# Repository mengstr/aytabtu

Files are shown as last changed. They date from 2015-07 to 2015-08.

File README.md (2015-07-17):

# AYTABTU

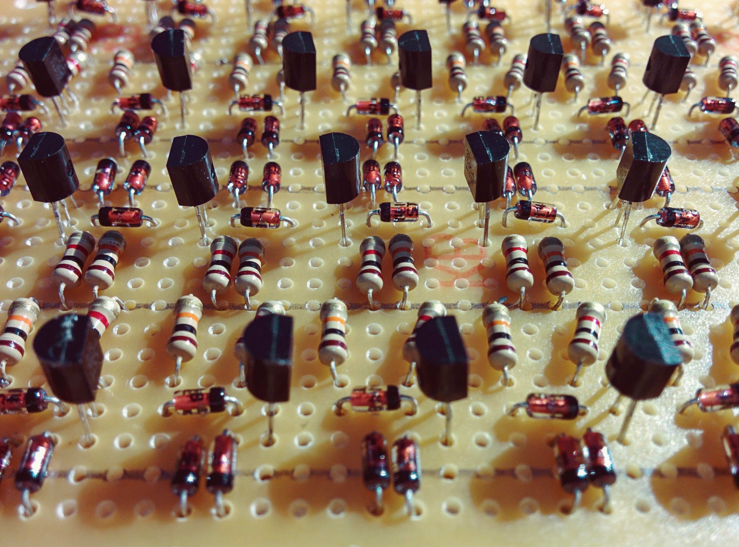
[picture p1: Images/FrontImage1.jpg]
Artful picture of a protoboard

**[All Your Transistors Are Belong to Us] - A computer built from discrete parts**

This is my attempt of building a complete computer using only discrete parts like transistors, diodes, capactitors and resistors.

Just to get warmed up a bit I've started designing an UART capable of transmiting and receiving serial data in 300 bps.

I plan to make proper PCBs for the boards that I require a lot of, like memory, registers and ALU-slices, but many of the more or less one-off boards will be made on standard donut-perfboard with thru-hole parts.

## Credits
I've used, collected, gleaned, stolen, borrowed and been inspired by the information on the following web sites:

Donut pcb layout creator - [code.google.com/p/diy-layout-creator/](https://code.google.com/p/diy-layout-creator/)  
Ring counter - [vk2zay.net/article/201](http://www.vk2zay.net/article/201)  
Asymetric multivibrator - [4qdtec.com/mvibs.html](http://www.4qdtec.com/mvibs.html)  
Single cycle CPU - [eecg.toronto.edu/~moshovos/ECE243-07/...](http://www.eecg.toronto.edu/~moshovos/ECE243-07/l19-implemenation-single-cycle.html)  
Binary incrementer - [letslearncomputing.blogspot.com/2013/....](http://letslearncomputing.blogspot.com/2013/03/digital-logic-4-bit-binary-incrementer.html)  
12/8bit cpu - [usti8bit.blogspot.com](usti8bit.blogspot.com/2015_03_01_archive.html)  
8bit ttl cpu - [digitarworld.uw.hu/ttlcpu.html](http://digitarworld.uw.hu/ttlcpu.html)  
ASAP3 Computer - [pong74ls.blogspot.com/...](http://pong74ls.blogspot.com/2013/11/asap-3-almost-simple-as-possible.html)  
Tiny Tim - [northdownfarm.co.uk/rory/tim/tinytim.htm](http://www.northdownfarm.co.uk/rory/tim/tinytim.htm) 

## Links to my own resources
Link to Google Sheets for a [TX faker generator](https://docs.google.com/spreadsheets/d/1nLxUwCidM7_CYKXSP2XA_T4spadFk9zQSKAtxVXUBSM/edit?usp=sharing).

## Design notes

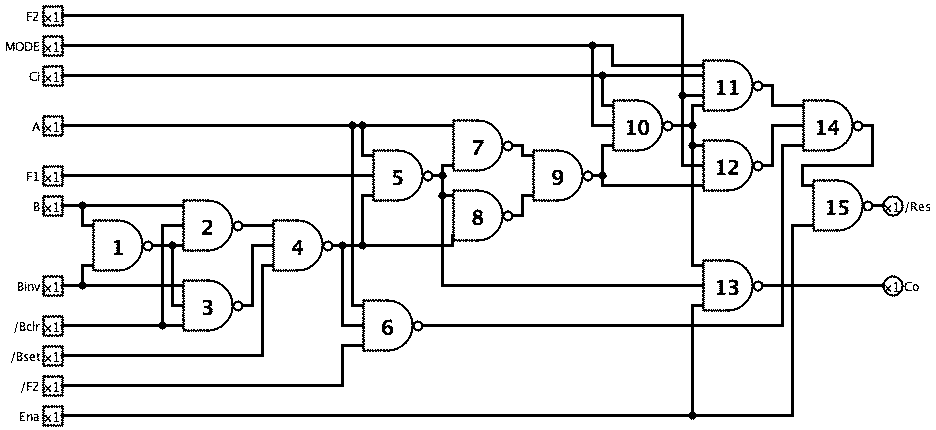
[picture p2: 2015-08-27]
Images/ALUslice.bmp

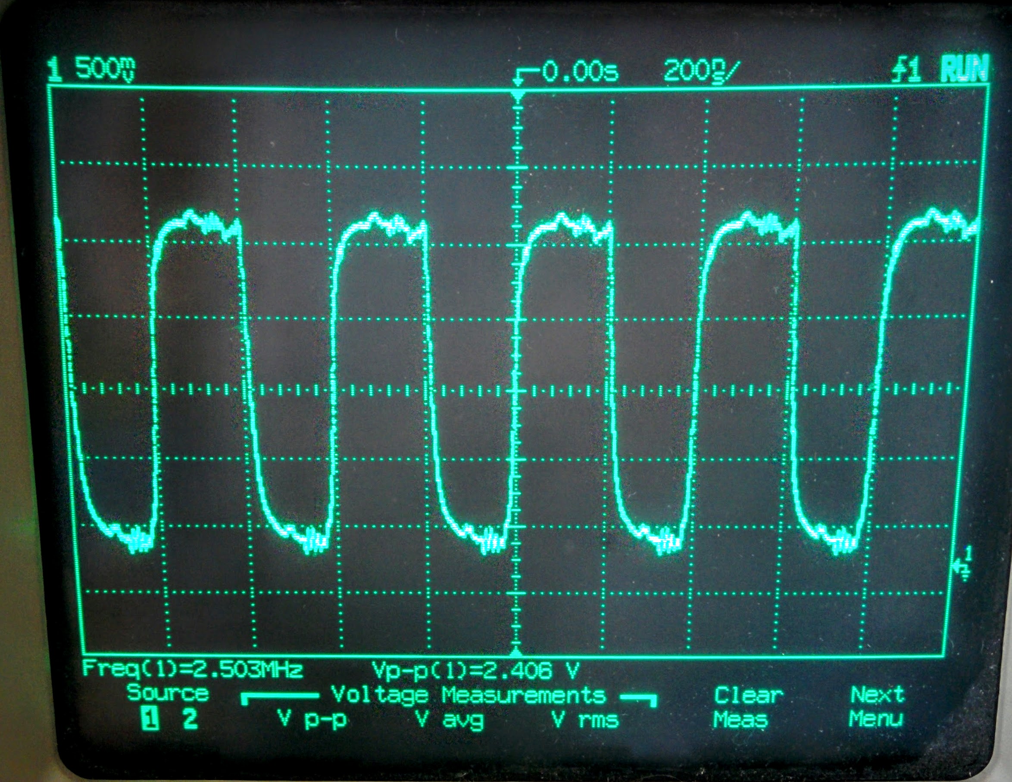
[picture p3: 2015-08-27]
Images/Osc2.5Mhz.jpg

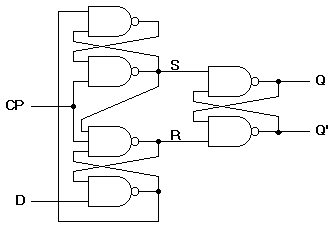
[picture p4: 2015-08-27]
Images/Edge_D_FlipFlop.gif

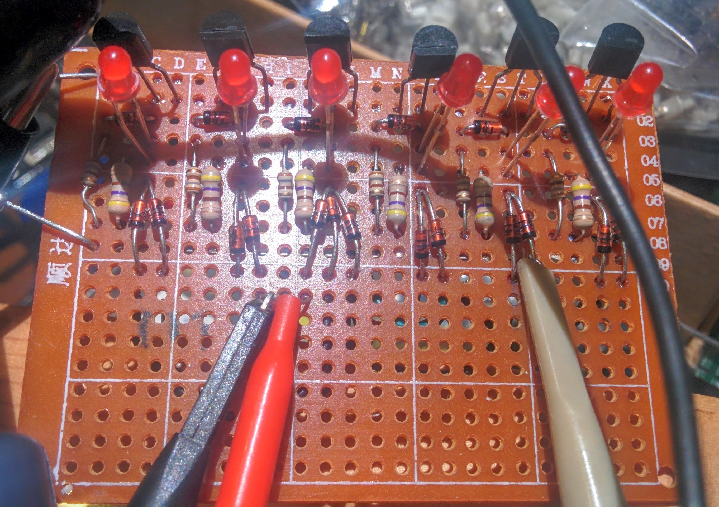
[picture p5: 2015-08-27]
Images/Divider-SiLED.jpg

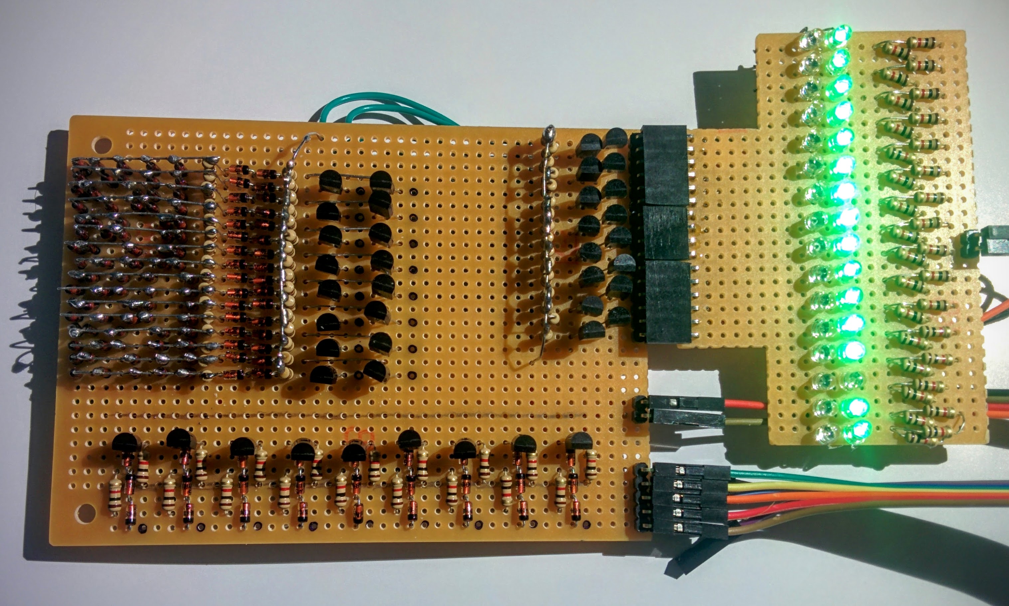
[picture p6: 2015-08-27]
Images/4-to-16decoder.jpg

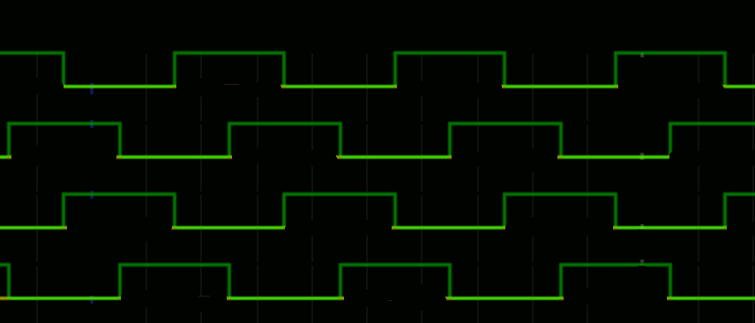
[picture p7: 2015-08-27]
Images/ClockGen4Phase2.png

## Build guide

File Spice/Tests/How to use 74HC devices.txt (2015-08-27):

Make a folder for your schematic(.asc) an save the schematic
into this folder.

Copy 74HC.lib into this folder.

Unzip 74HC.zip on any place. Copy the symbols you need into the
schematic folder.

Place the symbols in your schematic from the schematic folder.
Therefore change the symbol path to your schematic folder.
Press F2, then "Top Directory:your_schematic_path".

Place a SPICE-directive in your schematic.
.include 74HC.lib

Place a V-source with 5V on your schematic. Name it's net VCC.

If you want a logical "0", use a V-source with 0V.

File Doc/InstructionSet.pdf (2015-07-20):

ALU-OPS

0 A | 0 HALT | 0 SET 0x00 | 8 ADD
1 B | 1 | 1 SET 0xFF | 9 SUBTRACT
2 C | 2 | 2 INVERT | 10 ADD w Carry
3 D | 3 | 3 OR | 11 SUB w Carry
4 X | 4 | 4 AND | 12 LEFTSHIFT
5 Y | 5 | 5 XOR | 13 RIGHTSHIFT
6 JH | 6 | 6 INCREMENT | 14
7 JL | 7 | 7 DECREMENT | 15
BRANCH | 0 | 0 | c2 | c1 | c0 | o5 | o4 | o3 | o2 | o1 | o0
HALT | 0 | 0 | 0 | 0 | 0 | x | x | x | x | x | x
FREE1 | 0 | 0 | 0 | 0 | 1 | o5 | o4 | o3 | o2 | o1 | o0
NOP | 0 | 0 | 0 | 1 | 0 | x | x | x | x | x | x
SJMP | 0 | 0 | 0 | 1 | 1 | o5 | o4 | o3 | o2 | o1 | o0
BRAZ | 0 | 0 | 1 | 0 | 0 | o5 | o4 | o3 | o2 | o1 | o0
BRANZ | 0 | 0 | 1 | 0 | 1 | o5 | o4 | o3 | o2 | o1 | o0
BRAC | 0 | 0 | 1 | 1 | 0 | o5 | o4 | o3 | o2 | o1 | o0
BRANC | 0 | 0 | 1 | 1 | 1 | o5 | o4 | o3 | o2 | o1 | o0
LDAI | 0 | 1 | 0 | id7 | id6 | id5 | id4 | id3 | id2 | id1 | id0
LDAZP | 0 | 1 | 1 | a7 | a6 | a5 | a4 | a3 | a2 | a1 | a0
STAZP | 1 | 0 | 0 | a7 | a6 | a5 | a4 | a3 | a2 | a1 | a0
ALU | 1 | 0 | 1 | 0 | op3 | op2 | op1 | op0 | r2 | r1 | r0
CLR | 1 | 0 | 1 | 0 | 0 | 0 | 0 | 0 | r2 | r1 | r0 | r = 0x00
SETFF | 1 | 0 | 1 | 0 | 0 | 0 | 0 | 1 | r2 | r1 | r0 | r = 0xFF
NOT | 1 | 0 | 1 | 0 | 0 | 0 | 1 | 0 | r2 | r1 | r0
OR | 1 | 0 | 1 | 0 | 0 | 0 | 1 | 1 | r2 | r1 | r0 | r = r OR A
AND | 1 | 0 | 1 | 0 | 0 | 1 | 0 | 0 | r2 | r1 | r0 | r = r AND A
XOR | 1 | 0 | 1 | 0 | 0 | 1 | 0 | 1 | r2 | r1 | r0 | r = r XOR A
INC | 1 | 0 | 1 | 0 | 0 | 1 | 1 | 0 | r2 | r1 | r0 | r = r + 1
DEC | 1 | 0 | 1 | 0 | 0 | 1 | 1 | 1 | r2 | r1 | r0 | r = r - 1
ADD | 1 | 0 | 1 | 0 | 1 | 0 | 0 | 0 | r2 | r1 | r0 | r = r + A
SUB | 1 | 0 | 1 | 0 | 1 | 0 | 0 | 1 | r2 | r1 | r0 | r = r - A
ADDC | 1 | 0 | 1 | 0 | 1 | 0 | 1 | 0 | r2 | r1 | r0
SUBC | 1 | 0 | 1 | 0 | 1 | 0 | 1 | 1 | r2 | r1 | r0
LSHIFT | 1 | 0 | 1 | 0 | 1 | 1 | 0 | 0 | r2 | r1 | r0
RSHIFT | 1 | 0 | 1 | 0 | 1 | 1 | 0 | 1 | r2 | r1 | r0
LSHIFTC | 1 | 0 | 1 | 0 | 1 | 1 | 1 | 0 | r2 | r1 | r0
RSHIFTC | 1 | 0 | 1 | 0 | 1 | 1 | 1 | 1 | r2 | r1 | r0
MOVE | 1 | 0 | 1 | 1 | 0 | rs2 | rs1 | rs0 | rd2 | rd1 | rd0
TEST | 1 | 0 | 1 | 1 | 1 | b2 | b1 | b0 | r2 | r1 | r0
PEEK | 1 | 1 | 0 | 0 | 0 | 0 | 0 | p3 | p2 | p1 | p0
POKE | 1 | 1 | 0 | 0 | 0 | 0 | 1 | p3 | p2 | p1 | p0
LDAXY | 1 | 1 | 0 | 0 | 0 | 1 | 0 | 0 | 0 | 0 | 0
STAXY | 1 | 1 | 0 | 0 | 0 | 1 | 0 | 0 | 0 | 0 | 1
JUMP | 1 | 1 | 0 | 0 | 0 | 1 | 0 | 0 | 0 | 1 | 0
CALL | 1 | 1 | 0 | 0 | 0 | 1 | 0 | 0 | 0 | 1 | 1
RET | 1 | 1 | 0 | 0 | 0 | 1 | 0 | 0 | 1 | 0 | 0
| 1 | 1 | 0 | 0 | 0 | 1 | 0 | 0 | 1 | 0 | 1
CLRC | 1 | 1 | 0 | 0 | 0 | 1 | 0 | 0 | 1 | 1 | 0
SETC | 1 | 1 | 0 | 0 | 0 | 1 | 0 | 0 | 1 | 1 | 1
LDPML | 1 | 1 | 0 | 0 | 0 | 1 | 0 | 1 | 0 | 0 | 0
LDPMH | 1 | 1 | 0 | 0 | 0 | 1 | 0 | 1 | 0 | 0 | 1
STPML | 1 | 1 | 0 | 0 | 0 | 1 | 0 | 1 | 0 | 1 | 0
STPMH | 1 | 1 | 0 | 0 | 0 | 1 | 0 | 1 | 0 | 1 | 1
REGISTER | CONDITIONS

Main working register/accumulator

General register

General register | NEVER
General register | ALWAYS
General register/High memory pointer | Z-flag set
General register/Low memory pointer | Z-flag clear
High memory pointer for jumps/calls | C-flag set | LEFTSHIFT w Carry
Low memory pointer for jumps/call | C-flag clear | RIGHTSHIFT w Carry

Conditional "c" relative jump to (+/-)offset indicated by "o"

Stop execution

Do nothing, just continue execution

Jump between -31 and +32 bytes relative from PC

If Zeroflag=1 then jump between -31 and +32 bytes relative from PC

If Zeroflag=0 then jump between -31 and +32 bytes relative from PC

If Carry=1 then jump between -31 and +32 bytes relative from PC

If Carry=0 then jump between -31 and +32 bytes relative from PC

Load immediate data "id" into A

Load value of RAM in areas 0x00..0xFF into A

Store value of A into RAM in areas 0x00..0xFF

Perform the operation "op" on register "r"

r = r XOR 0xFF

r = r + A + carry

r = r - A - carry

r = r << 1, lsb=0

r = r >> 1, msb=0

r = r << 1, lsb=carry

r = r >> 1, msb=carry

Copy (move) register "rs" to register "rd"

Test if bit "b" is set in register "r" and update Z-flag

Load value of i/o port "p" into A

Store value of A into i/o port "p"

Load value of RAM pointed to by X/Y register pair into A-register

Store value of A into RAM pointed to by X/Y register pair

Jump to address pointed to by JH/JL

Jump to address pointed to by JH/JL, update PCHOLD with current PC

Return from CALL by loading PC with values from PCHOLD

Clear Carry flag

Set Clarry flag

Load Low byte (bit 0..7) from Program Memry pointed to by XY into A

Load High byte (bit 8..10) from Program Memry pointed to by XY into A

Store A into Low byte (bit 0..7) of Program memory pointed to by XY

Store A into High byte (bit 8..10) of Program memory pointed to by X

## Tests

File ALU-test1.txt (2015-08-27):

$ 1 0.000005 10.200277308269968 50 5 50
150 240 176 304 176 0 2 0
150 240 240 304 240 0 2 0
150 480 96 544 96 0 2 0
150 640 80 704 80 0 2 0
150 640 144 704 144 0 2 0
150 640 208 704 208 0 2 0
150 448 400 512 400 0 2 0
150 448 480 512 480 0 2 0
150 448 560 528 560 0 2 0
150 448 640 528 640 0 2 0
150 720 448 720 512 0 3 0
150 832 448 832 512 0 3 0
150 928 320 1008 320 0 2 0
154 336 160 416 160 0 2 0
154 704 320 768 320 0 2 0
154 832 304 896 304 0 2 0
152 880 112 960 112 0 4 0
152 480 176 544 176 0 2 0
152 768 576 768 640 0 2 0
I 480 240 544 240 0 0.5
I 320 384 384 384 0 0.5
I 320 416 384 416 0 0.5
I 336 464 384 464 0 0.5
I 320 576 368 576 0 0.5
w 704 80 880 80 0
w 880 96 736 96 0
w 736 96 736 144 0
w 736 144 704 144 0
w 704 208 752 208 0
w 752 208 752 128 0
w 752 128 880 128 0
w 304 176 320 176 0
w 320 176 336 176 0
w 240 160 160 160 0
w 240 192 160 192 0
w 240 224 160 224 0
w 240 256 160 256 0
w 480 240 464 240 0
w 464 240 464 192 0
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
L 160 32 144 32 0 0 false 5 0
L 160 128 144 128 0 0 false 5 0
L 160 160 144 160 0 0 false 5 0
L 160 192 144 192 0 0 false 5 0
L 160 224 144 224 0 0 false 5 0
L 160 256 144 256 0 0 false 5 0
L 160 464 144 464 0 0 false 5 0
L 160 576 144 576 0 0 false 5 0
M 1024 656 1040 656 0 2.5
M 1040 112 1056 112 0 2.5
x 160 26 182 29 0 24 Ci
x 162 123 208 126 0 24 invA
x 162 152 178 155 0 24 A
x 162 186 204 189 0 24 enA
x 163 218 179 221 0 24 B
x 160 249 202 252 0 24 enB
x 158 456 186 459 0 24 F0
x 157 568 185 571 0 24 F1
x 968 646 998 649 0 24 Co
x 986 101 1024 104 0 24 Out

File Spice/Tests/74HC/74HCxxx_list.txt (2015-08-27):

List of implemented ICs.
x implemented

74HC00 x
74HC01 
74HC02 x
74HC03 x
74HC04 x
74HC08 x
74HC10 x
74HC11 x
74HC14 x
74HC20 x
74HC21 x
74HC27 x
74HC30 x
74HC32 x
74HC42	
74HC51 x
74HC58 x
74HC73
74HC74 x
74HC75
74HC76
74HC85
74HC86 x
74HC93
74HC107 x
74HC109 x
74HC112 x
74HC113
74HC123 x
74HC123A x
74HC125 x
74HC126
74HC132 x
74HC133
74HC137
74HC138 x
74HC139 x
74HC147
74HC148
74HC151 x 
74HC153 x
74HC154
74HC155
74HC157 x
74HC158 
74HC160
74HC161 x
74HC163 x
74HC164 x
74HC165 x
74HC166 x
74HC173
74HC174
74HC175
74HC190
74HC191 x
74HC192
74HC193
74HC194 x
74HC195 x
74HC221 x
74HC221A x
74HC237
74HC238 x
74HC240
74HC241
74HC244
74HC245 x
74HC251 x 
74HC253 x
74HC257 x
74HC258
74HC259
74HC266
74HC273
74HC283 x
74HC294
74HC297
74HC299
74HC365
74HC366
74HC367
74HC368
74HC373 x
74HC374 x
74HC377
74HC390 x
74HC393 x
74HC533
74HC540
74HC541
74HC563
74HC564
74HC573 (74HC373)
74HC574 (74HC374)
74HC590
74HC595
74HC620
74HC640
74HC646
74HC670
74HC688
74HC698
74HC4017 x
7HC4538

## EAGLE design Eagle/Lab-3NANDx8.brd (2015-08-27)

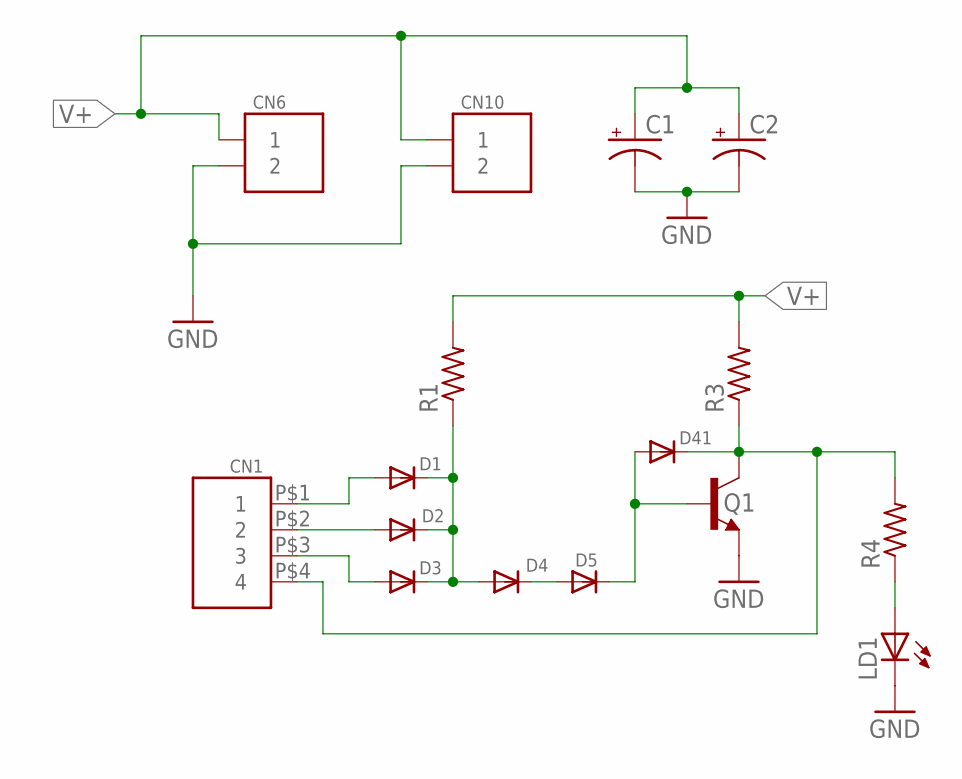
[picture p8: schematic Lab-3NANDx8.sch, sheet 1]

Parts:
C1, C2: CPOL-USE2.5-5; E2,5-5
CN1: HD4
CN6, CN10: HD2
D1, D2, D3, D4, D5: DIODE-6.3; DO35-6.3
D41: DIODE-7.6; DO35-7.6
LD1: LED3MM; 3MM
Q1: 2N3904-1; TO92BH
R1, R3, R4: R1/8-7.6MM; R0125-7.6

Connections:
GND: C1.-, C2.-, CN6.P$2 (2), CN10.P$2 (2), LD1.C, Q1.1 (E); also elsewhere on the board
unnamed: CN1.P$1 (1), D1.A
unnamed: CN1.P$2 (2), D2.A
unnamed: CN1.P$3 (3), D3.A
unnamed: D1.C, D2.C, D3.C, D4.A, R1.1
unnamed: D4.C, D5.A
unnamed: D5.C, D41.A, Q1.2 (B)
unnamed: LD1.A, R4.1
unnamed: CN1.P$4 (4), D41.C, Q1.3 (C), R3.1, R4.2
V+: C1.+, C2.+, CN6.P$1 (1), CN10.P$1 (1), R1.2, R3.2; also elsewhere on the board

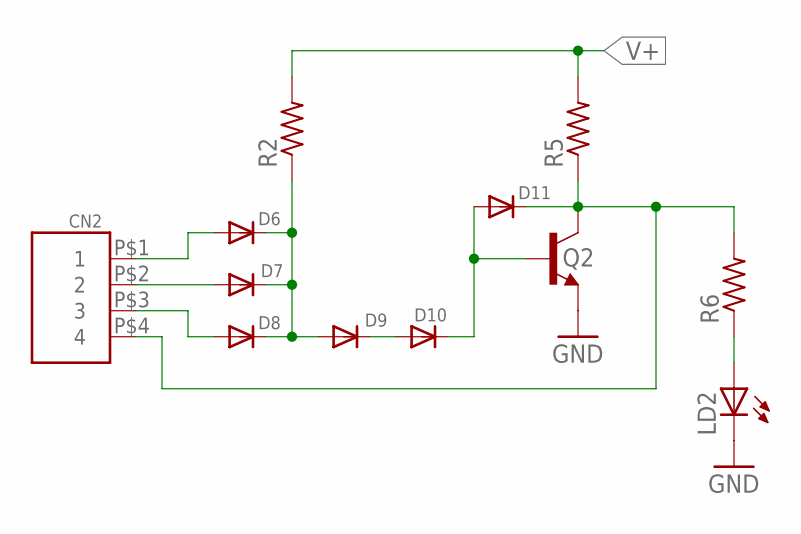
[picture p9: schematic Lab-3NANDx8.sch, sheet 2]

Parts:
CN2: HD4
D6, D7, D8, D9, D10: DIODE-6.3; DO35-6.3
D11: DIODE-7.6; DO35-7.6
LD2: LED3MM; 3MM
Q2: 2N3904-1; TO92BH
R2, R5, R6: R1/8-7.6MM; R0125-7.6

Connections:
GND: LD2.C, Q2.1 (E); also elsewhere on the board
unnamed: CN2.P$1 (1), D6.A
unnamed: CN2.P$2 (2), D7.A
unnamed: CN2.P$3 (3), D8.A
unnamed: D6.C, D7.C, D8.C, D9.A, R2.1
unnamed: D9.C, D10.A
unnamed: D10.C, D11.A, Q2.2 (B)
unnamed: CN2.P$4 (4), D11.C, Q2.3 (C), R5.1, R6.2
unnamed: LD2.A, R6.1
V+: R2.2, R5.2; also elsewhere on the board

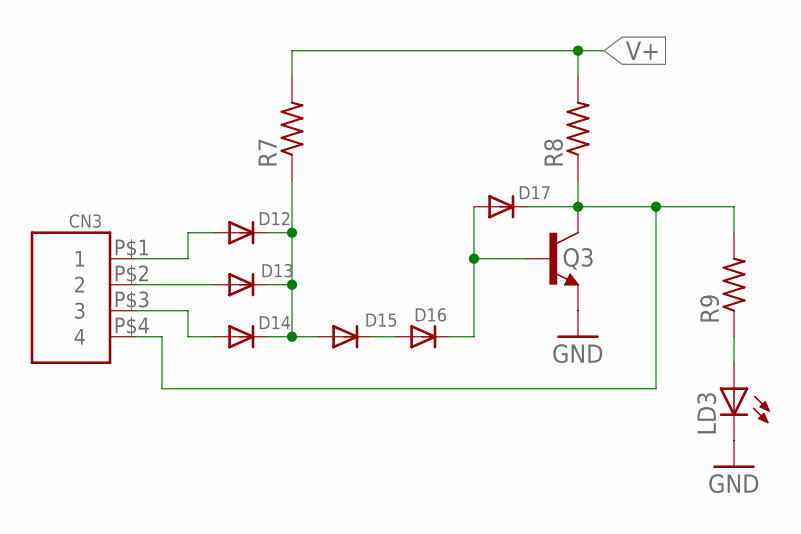
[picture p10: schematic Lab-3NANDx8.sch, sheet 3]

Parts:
CN3: HD4
D12, D13, D14, D15, D16: DIODE-6.3; DO35-6.3
D17: DIODE-7.6; DO35-7.6
LD3: LED3MM; 3MM
Q3: 2N3904-1; TO92BH
R7, R8, R9: R1/8-7.6MM; R0125-7.6

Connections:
GND: LD3.C, Q3.1 (E); also elsewhere on the board
unnamed: CN3.P$1 (1), D12.A
unnamed: CN3.P$2 (2), D13.A
unnamed: CN3.P$3 (3), D14.A
unnamed: D12.C, D13.C, D14.C, D15.A, R7.1
unnamed: D15.C, D16.A
unnamed: D16.C, D17.A, Q3.2 (B)
unnamed: CN3.P$4 (4), D17.C, Q3.3 (C), R8.1, R9.2
unnamed: LD3.A, R9.1
V+: R7.2, R8.2; also elsewhere on the board

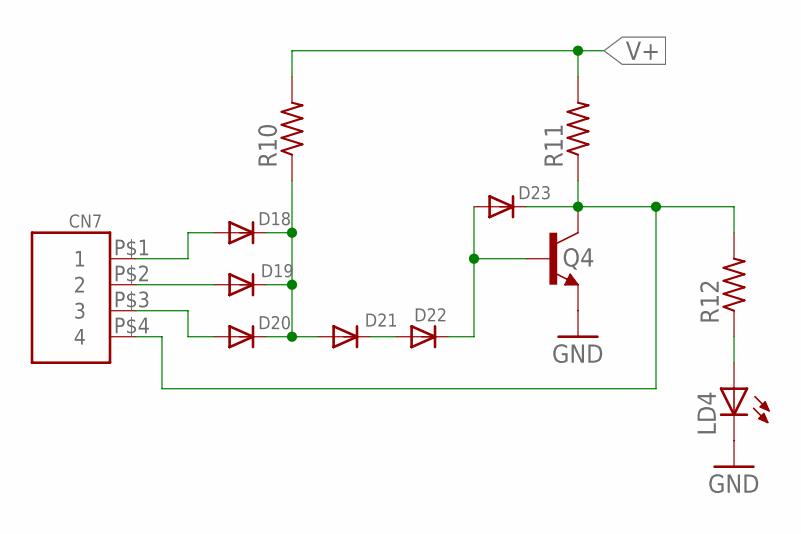
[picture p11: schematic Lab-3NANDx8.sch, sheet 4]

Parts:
CN7: HD4
D18, D19, D20, D21, D22: DIODE-6.3; DO35-6.3
D23: DIODE-7.6; DO35-7.6
LD4: LED3MM; 3MM
Q4: 2N3904-1; TO92BH
R10, R11, R12: R1/8-7.6MM; R0125-7.6

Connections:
GND: LD4.C, Q4.1 (E); also elsewhere on the board
unnamed: CN7.P$1 (1), D18.A
unnamed: CN7.P$2 (2), D19.A
unnamed: CN7.P$3 (3), D20.A
unnamed: D18.C, D19.C, D20.C, D21.A, R10.1
unnamed: D21.C, D22.A
unnamed: D22.C, D23.A, Q4.2 (B)
unnamed: CN7.P$4 (4), D23.C, Q4.3 (C), R11.1, R12.2
unnamed: LD4.A, R12.1
V+: R10.2, R11.2; also elsewhere on the board

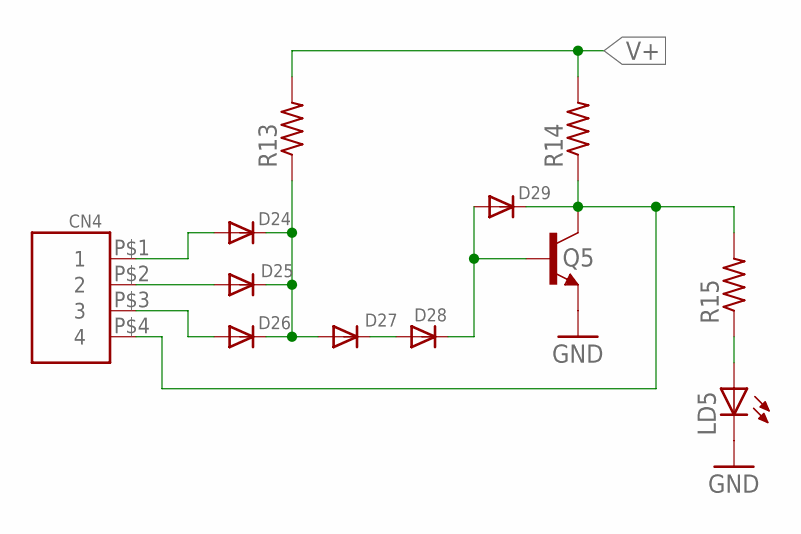
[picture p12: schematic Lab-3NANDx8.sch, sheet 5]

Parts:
CN4: HD4
D24, D25, D26, D27, D28: DIODE-6.3; DO35-6.3
D29: DIODE-7.6; DO35-7.6
LD5: LED3MM; 3MM
Q5: 2N3904-1; TO92BH
R13, R14, R15: R1/8-7.6MM; R0125-7.6

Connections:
GND: LD5.C, Q5.1 (E); also elsewhere on the board
unnamed: CN4.P$1 (1), D24.A
unnamed: CN4.P$2 (2), D25.A
unnamed: CN4.P$3 (3), D26.A
unnamed: D24.C, D25.C, D26.C, D27.A, R13.1
unnamed: D27.C, D28.A
unnamed: D28.C, D29.A, Q5.2 (B)
unnamed: CN4.P$4 (4), D29.C, Q5.3 (C), R14.1, R15.2
unnamed: LD5.A, R15.1
V+: R13.2, R14.2; also elsewhere on the board

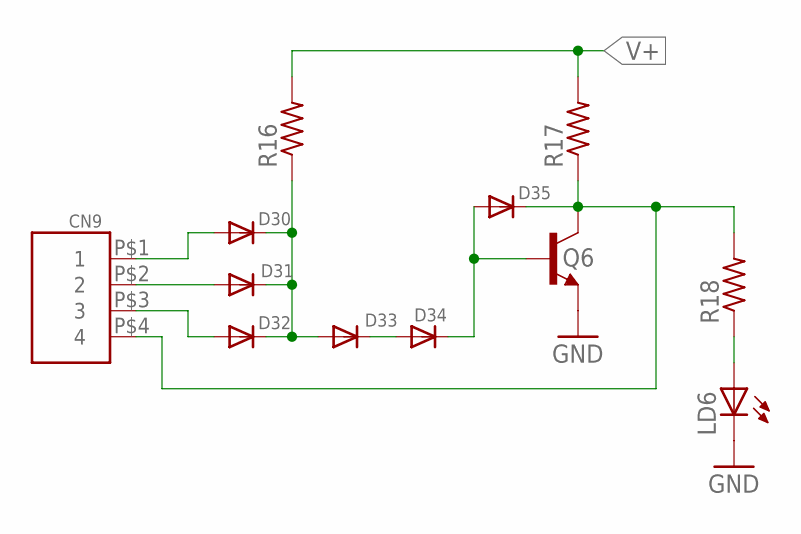
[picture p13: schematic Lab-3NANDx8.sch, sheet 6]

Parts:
CN9: HD4
D30, D31, D32, D33, D34: DIODE-6.3; DO35-6.3
D35: DIODE-7.6; DO35-7.6
LD6: LED3MM; 3MM
Q6: 2N3904-1; TO92BH
R16, R17, R18: R1/8-7.6MM; R0125-7.6

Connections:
GND: LD6.C, Q6.1 (E); also elsewhere on the board
unnamed: CN9.P$1 (1), D30.A
unnamed: CN9.P$2 (2), D31.A
unnamed: CN9.P$3 (3), D32.A
unnamed: D30.C, D31.C, D32.C, D33.A, R16.1
unnamed: D33.C, D34.A
unnamed: D34.C, D35.A, Q6.2 (B)
unnamed: CN9.P$4 (4), D35.C, Q6.3 (C), R17.1, R18.2
unnamed: LD6.A, R18.1
V+: R16.2, R17.2; also elsewhere on the board

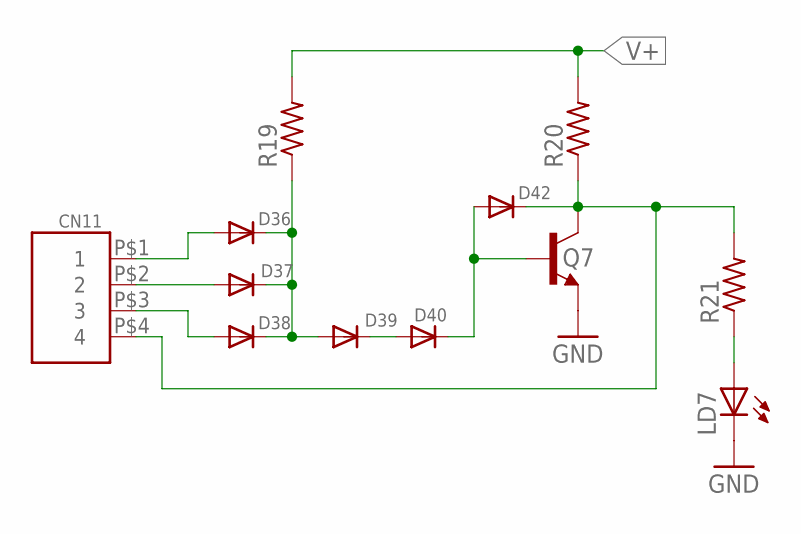
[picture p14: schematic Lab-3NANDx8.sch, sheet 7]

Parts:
CN11: HD4
D36, D37, D38, D39, D40: DIODE-6.3; DO35-6.3
D42: DIODE-7.6; DO35-7.6
LD7: LED3MM; 3MM
Q7: 2N3904-1; TO92BH
R19, R20, R21: R1/8-7.6MM; R0125-7.6

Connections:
GND: LD7.C, Q7.1 (E); also elsewhere on the board
unnamed: CN11.P$1 (1), D36.A
unnamed: CN11.P$2 (2), D37.A
unnamed: CN11.P$3 (3), D38.A
unnamed: D36.C, D37.C, D38.C, D39.A, R19.1
unnamed: D39.C, D40.A
unnamed: D40.C, D42.A, Q7.2 (B)
unnamed: CN11.P$4 (4), D42.C, Q7.3 (C), R20.1, R21.2
unnamed: LD7.A, R21.1
V+: R19.2, R20.2; also elsewhere on the board

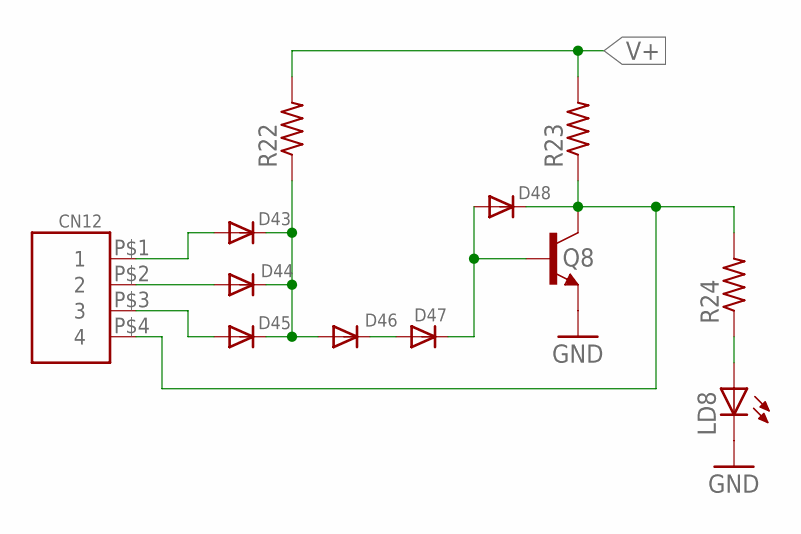
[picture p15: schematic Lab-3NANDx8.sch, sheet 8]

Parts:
CN12: HD4
D43, D44, D45, D46, D47: DIODE-6.3; DO35-6.3
D48: DIODE-7.6; DO35-7.6
LD8: LED3MM; 3MM
Q8: 2N3904-1; TO92BH
R22, R23, R24: R1/8-7.6MM; R0125-7.6

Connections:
GND: LD8.C, Q8.1 (E); also elsewhere on the board
unnamed: CN12.P$1 (1), D43.A
unnamed: CN12.P$2 (2), D44.A
unnamed: CN12.P$3 (3), D45.A
unnamed: D43.C, D44.C, D45.C, D46.A, R22.1
unnamed: D46.C, D47.A
unnamed: D47.C, D48.A, Q8.2 (B)
unnamed: CN12.P$4 (4), D48.C, Q8.3 (C), R23.1, R24.2
unnamed: LD8.A, R24.1
V+: R22.2, R23.2; also elsewhere on the board

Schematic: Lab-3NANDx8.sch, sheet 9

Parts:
CN5: HD4
D49, D50, D51, D52, D53: DIODE-6.3; DO35-6.3
D54: DIODE-7.6; DO35-7.6
LD9: LED3MM; 3MM
Q9: 2N3904-1; TO92BH
R25, R26, R27: R1/8-7.6MM; R0125-7.6

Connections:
GND: LD9.C, Q9.1 (E); also elsewhere on the board
unnamed: CN5.P$1 (1), D49.A
unnamed: CN5.P$2 (2), D50.A
unnamed: CN5.P$3 (3), D51.A
unnamed: D49.C, D50.C, D51.C, D52.A, R25.1
unnamed: D52.C, D53.A
unnamed: D53.C, D54.A, Q9.2 (B)
unnamed: CN5.P$4 (4), D54.C, Q9.3 (C), R26.1, R27.2
unnamed: LD9.A, R27.1
V+: R25.2, R26.2; also elsewhere on the board

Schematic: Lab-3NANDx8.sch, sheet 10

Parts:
CN14: HD4
D55, D56, D57, D58, D59: DIODE-6.3; DO35-6.3
D60: DIODE-7.6; DO35-7.6
LD10: LED3MM; 3MM
Q10: 2N3904-1; TO92BH
R28, R29, R30: R1/8-7.6MM; R0125-7.6

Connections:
GND: LD10.C, Q10.1 (E); also elsewhere on the board
unnamed: CN14.P$1 (1), D55.A
unnamed: CN14.P$2 (2), D56.A
unnamed: CN14.P$3 (3), D57.A
unnamed: D55.C, D56.C, D57.C, D58.A, R28.1
unnamed: D58.C, D59.A
unnamed: D59.C, D60.A, Q10.2 (B)
unnamed: CN14.P$4 (4), D60.C, Q10.3 (C), R29.1, R30.2
unnamed: LD10.A, R30.1
V+: R28.2, R29.2; also elsewhere on the board

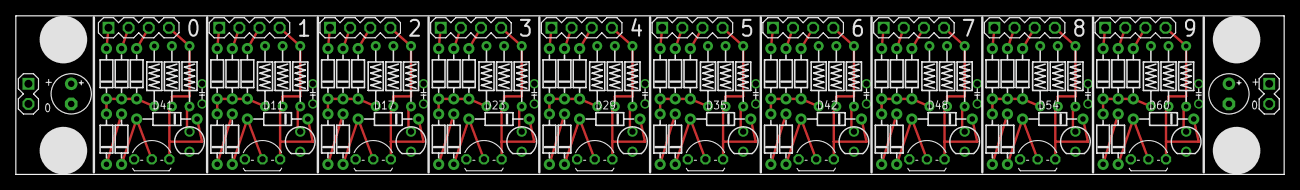
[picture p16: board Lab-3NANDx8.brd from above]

Board: 2 copper layers, 160.0 x 20.0 mm, 124 parts (0 on the bottom side), 82 nets.

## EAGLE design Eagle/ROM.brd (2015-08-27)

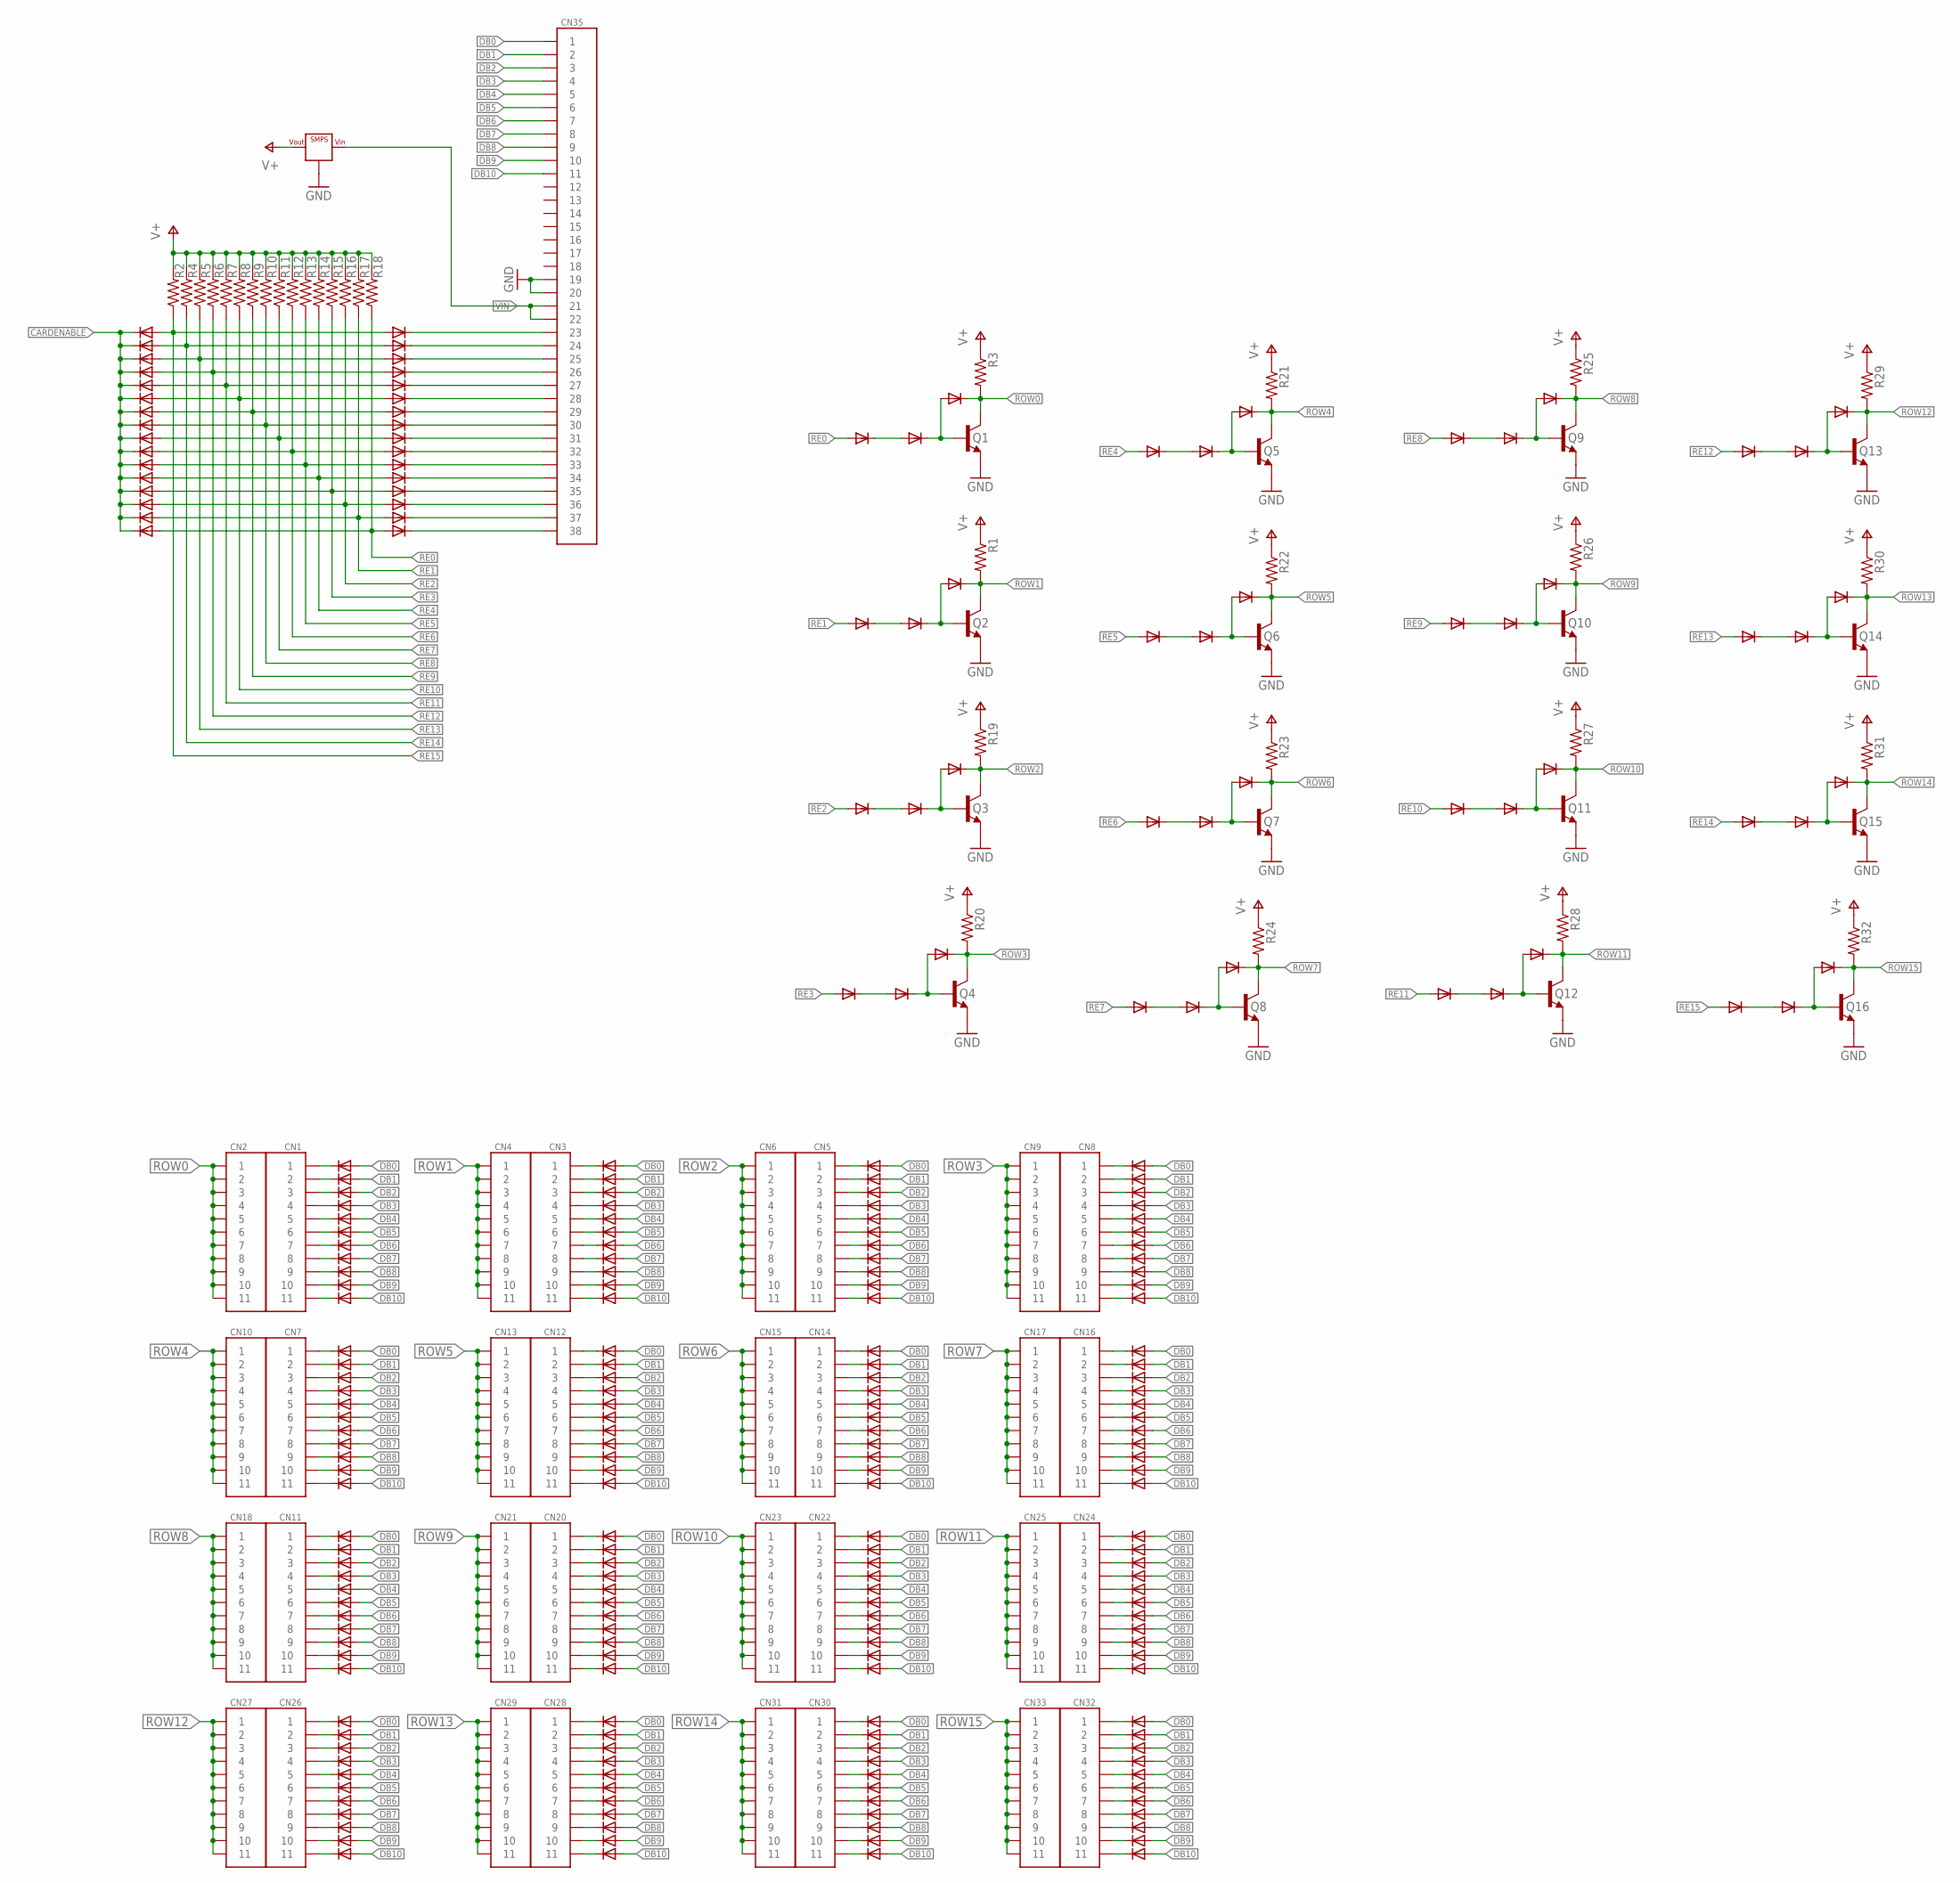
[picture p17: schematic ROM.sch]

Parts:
CN1, CN2, CN3, CN4, CN5, CN6, CN7, CN8, CN9, CN10, CN11, CN12, CN13, CN14, CN15, CN16, CN17, CN18, CN20, CN21, CN22, CN23, CN24, CN25, CN26, CN27, CN28, CN29, CN30, CN31, CN32, CN33: HD11
CN35: HD38-HP; HD38-HOLEPAD
D1, D2, D3, D4, D5, D6, D7, D8, D9, D10, D11, D12, D13, D14, D15, D16, D17, D18, D19, D20, D21, D22, D23, D24, D25, D26, D27, D28, D29, D30, D31, D32, D33, D34, D35, D36, D37, D38, D39, D40, D41, D42, D43, D44, D45, D46, D47, D48, D49, D50, D51, D52, D53, D54, D55, D56, D57, D58, D59, D60, D61, D62, D63, D64, D65, D66, D67, D68, D69, D70, D71, D72, D73, D74, D75, D76, D77, D78, D79, D80, D81, D82, D83, D84, D85, D86, D87, D88, D89, D90, D91, D92, D93, D94, D95, D96, D97, D98, D99, D100, D101, D102, D103, D104, D105, D106, D107, D108, D109, D110, D111, D112, D113, D114, D115, D116, D117, D118, D119, D120, D121, D122, D123, D124, D125, D126, D127, D128, D129, D130, D131, D132, D133, D134, D135, D136, D137, D138, D139, D140, D141, D142, D143, D144, D145, D146, D147, D148, D149, D150, D151, D152, D153, D154, D155, D156, D157, D158, D159, D160, D161, D162, D163, D164, D165, D166, D167, D168, D169, D170, D171, D172, D173, D174, D175, D176: DIODE-6.3; DO35-6.3
D177, D178, D179, D180, D181, D182, D183, D184, D185, D186, D187, D188, D189, D190, D191, D192, D193, D194, D195, D196, D197, D198, D199, D200, D201, D202, D203, D204, D205, D206, D207, D208, D209, D210, D211, D212, D213, D214, D215, D216, D217, D218, D219, D220, D221, D222, D223, D224, D225, D226, D227, D228, D229, D230, D231, D232, D233, D234, D235, D236, D237, D238, D239, D240, D241, D242, D243, D244, D245, D246, D247, D248, D249, D250, D251, D252, D253, D254, D255, D256: DIODE-5.08; DO35-5.08
Q1, Q2, Q3, Q4, Q5, Q6, Q7, Q8, Q9, Q10, Q11, Q12, Q13, Q14, Q15, Q16: BC547-STRAIGHT; TO92-S-CBE
R1, R2, R3, R4, R5, R6, R7, R8, R9, R10, R11, R12, R13, R14, R15, R16, R17, R18, R19, R20, R21, R22, R23, R24, R25, R26, R27, R28, R29, R30, R31, R32: R1/8-6MM; R0125-6.3
VR1: SMPS; BUCK1722

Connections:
CARDENABLE: D182.C, D183.C, D184.C, D185.C, D186.C, D187.C, D188.C, D189.C, D190.C, D191.C, D192.C, D193.C, D194.C, D195.C, D196.C, D197.C
DB0: CN35.P1@1 (1), CN35.P1@2 (1), D1.A, D12.A, D23.A, D34.A, D45.A, D56.A, D67.A, D78.A, D89.A, D100.A, D111.A, D122.A, D133.A, D144.A, D155.A, D166.A
DB1: CN35.P2@1 (2), CN35.P2@2 (2), D2.A, D13.A, D24.A, D35.A, D46.A, D57.A, D68.A, D79.A, D90.A, D101.A, D112.A, D123.A, D134.A, D145.A, D156.A, D167.A
DB2: CN35.P3@1 (3), CN35.P3@2 (3), D3.A, D14.A, D25.A, D36.A, D47.A, D58.A, D69.A, D80.A, D91.A, D102.A, D113.A, D124.A, D135.A, D146.A, D157.A, D168.A
DB3: CN35.P4@1 (4), CN35.P4@2 (4), D4.A, D15.A, D26.A, D37.A, D48.A, D59.A, D70.A, D81.A, D92.A, D103.A, D114.A, D125.A, D136.A, D147.A, D158.A, D169.A
DB4: CN35.P5@1 (5), CN35.P5@2 (5), D5.A, D16.A, D27.A, D38.A, D49.A, D60.A, D71.A, D82.A, D93.A, D104.A, D115.A, D126.A, D137.A, D148.A, D159.A, D170.A
DB5: CN35.P6@1 (6), CN35.P6@2 (6), D6.A, D17.A, D28.A, D39.A, D50.A, D61.A, D72.A, D83.A, D94.A, D105.A, D116.A, D127.A, D138.A, D149.A, D160.A, D171.A
DB6: CN35.P7@1 (7), CN35.P7@2 (7), D7.A, D18.A, D29.A, D40.A, D51.A, D62.A, D73.A, D84.A, D95.A, D106.A, D117.A, D128.A, D139.A, D150.A, D161.A, D172.A
DB7: CN35.P8@1 (8), CN35.P8@2 (8), D8.A, D19.A, D30.A, D41.A, D52.A, D63.A, D74.A, D85.A, D96.A, D107.A, D118.A, D129.A, D140.A, D151.A, D162.A, D173.A
DB8: CN35.P9@1 (9), CN35.P9@2 (9), D9.A, D20.A, D31.A, D42.A, D53.A, D64.A, D75.A, D86.A, D97.A, D108.A, D119.A, D130.A, D141.A, D152.A, D163.A, D174.A
DB9: CN35.P10@1 (10), CN35.P10@2 (10), D10.A, D21.A, D32.A, D43.A, D54.A, D65.A, D76.A, D87.A, D98.A, D109.A, D120.A, D131.A, D142.A, D153.A, D164.A, D175.A
DB10: CN35.P11@1 (11), CN35.P11@2 (11), D11.A, D22.A, D33.A, D44.A, D55.A, D66.A, D77.A, D88.A, D99.A, D110.A, D121.A, D132.A, D143.A, D154.A, D165.A, D176.A
GND: CN35.P19@1 (19), CN35.P19@2 (19), CN35.P20@1 (20), CN35.P20@2 (20), Q1.E, Q2.E, Q3.E, Q4.E, Q5.E, Q6.E, Q7.E, Q8.E, Q9.E, Q10.E, Q11.E, Q12.E, Q13.E, Q14.E, Q15.E, Q16.E, VR1.GND@1 (GND), VR1.GND@2 (GND), VR1.GND@3 (GND), VR1.GND@4 (GND)
unnamed: CN1.P$1 (1), D1.C
unnamed: CN1.P$2 (2), D2.C
unnamed: CN1.P$3 (3), D3.C
unnamed: CN1.P$4 (4), D4.C
unnamed: CN1.P$5 (5), D5.C
unnamed: CN1.P$6 (6), D6.C
unnamed: CN1.P$7 (7), D7.C
unnamed: CN1.P$8 (8), D8.C
unnamed: CN1.P$9 (9), D9.C
unnamed: CN1.P$10 (10), D10.C
unnamed: CN1.P$11 (11), D11.C
unnamed: CN3.P$1 (1), D12.C
unnamed: CN3.P$2 (2), D13.C
unnamed: CN3.P$3 (3), D14.C
unnamed: CN3.P$4 (4), D15.C
unnamed: CN3.P$5 (5), D16.C
unnamed: CN3.P$6 (6), D17.C
unnamed: CN3.P$7 (7), D18.C
unnamed: CN3.P$8 (8), D19.C
unnamed: CN3.P$9 (9), D20.C
unnamed: CN3.P$10 (10), D21.C
unnamed: CN3.P$11 (11), D22.C
unnamed: CN5.P$1 (1), D23.C
unnamed: CN5.P$2 (2), D24.C
unnamed: CN5.P$3 (3), D25.C
unnamed: CN5.P$4 (4), D26.C
unnamed: CN5.P$5 (5), D27.C
unnamed: CN5.P$6 (6), D28.C
unnamed: CN5.P$7 (7), D29.C
unnamed: CN5.P$8 (8), D30.C
unnamed: CN5.P$9 (9), D31.C
unnamed: CN5.P$10 (10), D32.C
unnamed: CN5.P$11 (11), D33.C
unnamed: CN8.P$1 (1), D34.C
unnamed: CN8.P$2 (2), D35.C
unnamed: CN8.P$3 (3), D36.C
unnamed: CN8.P$4 (4), D37.C
unnamed: CN8.P$5 (5), D38.C
unnamed: CN8.P$6 (6), D39.C
unnamed: CN8.P$7 (7), D40.C
unnamed: CN8.P$8 (8), D41.C
unnamed: CN8.P$9 (9), D42.C
unnamed: CN8.P$10 (10), D43.C
unnamed: CN8.P$11 (11), D44.C
unnamed: CN7.P$1 (1), D45.C
unnamed: CN7.P$2 (2), D46.C
unnamed: CN7.P$3 (3), D47.C
unnamed: CN7.P$4 (4), D48.C
unnamed: CN7.P$5 (5), D49.C
unnamed: CN7.P$6 (6), D50.C
unnamed: CN7.P$7 (7), D51.C
unnamed: CN7.P$8 (8), D52.C
unnamed: CN7.P$9 (9), D53.C
unnamed: CN7.P$10 (10), D54.C
unnamed: CN7.P$11 (11), D55.C
unnamed: CN12.P$1 (1), D56.C
unnamed: CN12.P$2 (2), D57.C
unnamed: CN12.P$3 (3), D58.C
unnamed: CN12.P$4 (4), D59.C
unnamed: CN12.P$5 (5), D60.C
unnamed: CN12.P$6 (6), D61.C
unnamed: CN12.P$7 (7), D62.C
unnamed: CN12.P$8 (8), D63.C
unnamed: CN12.P$9 (9), D64.C
unnamed: CN12.P$10 (10), D65.C
unnamed: CN12.P$11 (11), D66.C
unnamed: CN14.P$1 (1), D67.C
unnamed: CN14.P$2 (2), D68.C
unnamed: CN14.P$3 (3), D69.C
unnamed: CN14.P$4 (4), D70.C
unnamed: CN14.P$5 (5), D71.C
unnamed: CN14.P$6 (6), D72.C
unnamed: CN14.P$7 (7), D73.C
unnamed: CN14.P$8 (8), D74.C
unnamed: CN14.P$9 (9), D75.C
unnamed: CN14.P$10 (10), D76.C
unnamed: CN14.P$11 (11), D77.C
unnamed: CN16.P$1 (1), D78.C
unnamed: CN16.P$2 (2), D79.C
unnamed: CN16.P$3 (3), D80.C
unnamed: CN16.P$4 (4), D81.C
unnamed: CN16.P$5 (5), D82.C
unnamed: CN16.P$6 (6), D83.C
unnamed: CN16.P$7 (7), D84.C
unnamed: CN16.P$8 (8), D85.C
unnamed: CN16.P$9 (9), D86.C
unnamed: CN16.P$10 (10), D87.C
unnamed: CN16.P$11 (11), D88.C
unnamed: CN11.P$1 (1), D89.C
unnamed: CN11.P$2 (2), D90.C
unnamed: CN11.P$3 (3), D91.C
unnamed: CN11.P$4 (4), D92.C
unnamed: CN11.P$5 (5), D93.C
unnamed: CN11.P$6 (6), D94.C
unnamed: CN11.P$7 (7), D95.C
unnamed: CN11.P$8 (8), D96.C
unnamed: CN11.P$9 (9), D97.C
unnamed: CN11.P$10 (10), D98.C
unnamed: CN11.P$11 (11), D99.C
unnamed: CN20.P$1 (1), D100.C
unnamed: CN20.P$2 (2), D101.C
unnamed: CN20.P$3 (3), D102.C
unnamed: CN20.P$4 (4), D103.C
unnamed: CN20.P$5 (5), D104.C
unnamed: CN20.P$6 (6), D105.C
unnamed: CN20.P$7 (7), D106.C
unnamed: CN20.P$8 (8), D107.C
unnamed: CN20.P$9 (9), D108.C
unnamed: CN20.P$10 (10), D109.C
unnamed: CN20.P$11 (11), D110.C
unnamed: CN22.P$1 (1), D111.C
unnamed: CN22.P$2 (2), D112.C
unnamed: CN22.P$3 (3), D113.C
unnamed: CN22.P$4 (4), D114.C
unnamed: CN22.P$5 (5), D115.C
unnamed: CN22.P$6 (6), D116.C
unnamed: CN22.P$7 (7), D117.C
unnamed: CN22.P$8 (8), D118.C
unnamed: CN22.P$9 (9), D119.C
unnamed: CN22.P$10 (10), D120.C
unnamed: CN22.P$11 (11), D121.C
unnamed: CN24.P$1 (1), D122.C
unnamed: CN24.P$2 (2), D123.C
unnamed: CN24.P$3 (3), D124.C
unnamed: CN24.P$4 (4), D125.C
unnamed: CN24.P$5 (5), D126.C
unnamed: CN24.P$6 (6), D127.C
unnamed: CN24.P$7 (7), D128.C
unnamed: CN24.P$8 (8), D129.C
unnamed: CN24.P$9 (9), D130.C
unnamed: CN24.P$10 (10), D131.C
unnamed: CN24.P$11 (11), D132.C
unnamed: CN26.P$1 (1), D133.C
unnamed: CN26.P$2 (2), D134.C
unnamed: CN26.P$3 (3), D135.C
unnamed: CN26.P$4 (4), D136.C
unnamed: CN26.P$5 (5), D137.C
unnamed: CN26.P$6 (6), D138.C
unnamed: CN26.P$7 (7), D139.C
unnamed: CN26.P$8 (8), D140.C
unnamed: CN26.P$9 (9), D141.C
unnamed: CN26.P$10 (10), D142.C
unnamed: CN26.P$11 (11), D143.C
unnamed: CN28.P$1 (1), D144.C
unnamed: CN28.P$2 (2), D145.C
unnamed: CN28.P$3 (3), D146.C
unnamed: CN28.P$4 (4), D147.C
unnamed: CN28.P$5 (5), D148.C
unnamed: CN28.P$6 (6), D149.C
unnamed: CN28.P$7 (7), D150.C
unnamed: CN28.P$8 (8), D151.C
unnamed: CN28.P$9 (9), D152.C
unnamed: CN28.P$10 (10), D153.C
unnamed: CN28.P$11 (11), D154.C
unnamed: CN30.P$1 (1), D155.C
unnamed: CN30.P$2 (2), D156.C
unnamed: CN30.P$3 (3), D157.C
unnamed: CN30.P$4 (4), D158.C
unnamed: CN30.P$5 (5), D159.C
unnamed: CN30.P$6 (6), D160.C
unnamed: CN30.P$7 (7), D161.C
unnamed: CN30.P$8 (8), D162.C
unnamed: CN30.P$9 (9), D163.C
unnamed: CN30.P$10 (10), D164.C
unnamed: CN30.P$11 (11), D165.C
unnamed: CN32.P$1 (1), D166.C
unnamed: CN32.P$2 (2), D167.C
unnamed: CN32.P$3 (3), D168.C
unnamed: CN32.P$4 (4), D169.C
unnamed: CN32.P$5 (5), D170.C
unnamed: CN32.P$6 (6), D171.C
unnamed: CN32.P$7 (7), D172.C
unnamed: CN32.P$8 (8), D173.C
unnamed: CN32.P$9 (9), D174.C
unnamed: CN32.P$10 (10), D175.C
unnamed: CN32.P$11 (11), D176.C
unnamed: D215.A, D216.C
unnamed: D177.C, D181.A, Q1.B
unnamed: D177.A, D178.C
unnamed: D212.C, D214.A, Q2.B
unnamed: D212.A, D213.C
unnamed: D215.C, D217.A, Q3.B
unnamed: D242.A, D243.C
unnamed: D218.C, D220.A, Q4.B
unnamed: D218.A, D219.C
unnamed: D221.C, D223.A, Q5.B
unnamed: D221.A, D222.C
unnamed: D224.C, D226.A, Q6.B
unnamed: D224.A, D225.C
unnamed: D227.C, D229.A, Q7.B
unnamed: D227.A, D228.C
unnamed: D230.C, D232.A, Q8.B
unnamed: D230.A, D231.C
unnamed: D233.C, D235.A, Q9.B
unnamed: D233.A, D234.C
unnamed: D236.C, D238.A, Q10.B
unnamed: D239.C, D241.A, Q11.B
unnamed: D239.A, D240.C
unnamed: D242.C, D244.A, Q12.B
unnamed: D251.A, D252.C
unnamed: D245.C, D247.A, Q13.B
unnamed: D236.A, D237.C
unnamed: D248.C, D250.A, Q14.B
unnamed: D245.A, D246.C
unnamed: D251.C, D253.A, Q15.B
unnamed: D248.A, D249.C
unnamed: D254.C, D256.A, Q16.B
unnamed: D254.A, D255.C
RE0: D178.A, D197.A, D211.A, R18.1
RE1: D196.A, D210.A, D213.A, R17.1
RE2: D195.A, D209.A, D216.A, R16.1
RE3: D194.A, D208.A, D219.A, R15.1
RE4: D193.A, D207.A, D222.A, R14.1
RE5: D192.A, D206.A, D225.A, R13.1
RE6: D191.A, D205.A, D228.A, R12.1
RE7: D190.A, D204.A, D231.A, R11.1
RE8: D189.A, D203.A, D234.A, R10.1
RE9: D188.A, D202.A, D237.A, R9.1
RE10: D187.A, D201.A, D240.A, R8.1
RE11: D186.A, D200.A, D243.A, R7.1
RE12: D185.A, D199.A, D246.A, R6.1
RE13: D184.A, D198.A, D249.A, R5.1
RE14: D180.A, D183.A, D252.A, R4.1
RE15: D179.A, D182.A, D255.A, R2.1
ROW0: CN2.P$1 (1), CN2.P$2 (2), CN2.P$3 (3), CN2.P$4 (4), CN2.P$5 (5), CN2.P$6 (6), CN2.P$7 (7), CN2.P$8 (8), CN2.P$9 (9), CN2.P$10 (10), CN2.P$11 (11), D181.C, Q1.C, R3.2
ROW1: CN4.P$1 (1), CN4.P$2 (2), CN4.P$3 (3), CN4.P$4 (4), CN4.P$5 (5), CN4.P$6 (6), CN4.P$7 (7), CN4.P$8 (8), CN4.P$9 (9), CN4.P$10 (10), CN4.P$11 (11), D214.C, Q2.C, R1.2
ROW2: CN6.P$1 (1), CN6.P$2 (2), CN6.P$3 (3), CN6.P$4 (4), CN6.P$5 (5), CN6.P$6 (6), CN6.P$7 (7), CN6.P$8 (8), CN6.P$9 (9), CN6.P$10 (10), CN6.P$11 (11), D217.C, Q3.C, R19.2
ROW3: CN9.P$1 (1), CN9.P$2 (2), CN9.P$3 (3), CN9.P$4 (4), CN9.P$5 (5), CN9.P$6 (6), CN9.P$7 (7), CN9.P$8 (8), CN9.P$9 (9), CN9.P$10 (10), CN9.P$11 (11), D220.C, Q4.C, R20.2
ROW4: CN10.P$1 (1), CN10.P$2 (2), CN10.P$3 (3), CN10.P$4 (4), CN10.P$5 (5), CN10.P$6 (6), CN10.P$7 (7), CN10.P$8 (8), CN10.P$9 (9), CN10.P$10 (10), CN10.P$11 (11), D223.C, Q5.C, R21.2
ROW5: CN13.P$1 (1), CN13.P$2 (2), CN13.P$3 (3), CN13.P$4 (4), CN13.P$5 (5), CN13.P$6 (6), CN13.P$7 (7), CN13.P$8 (8), CN13.P$9 (9), CN13.P$10 (10), CN13.P$11 (11), D226.C, Q6.C, R22.2
ROW6: CN15.P$1 (1), CN15.P$2 (2), CN15.P$3 (3), CN15.P$4 (4), CN15.P$5 (5), CN15.P$6 (6), CN15.P$7 (7), CN15.P$8 (8), CN15.P$9 (9), CN15.P$10 (10), CN15.P$11 (11), D229.C, Q7.C, R23.2
ROW7: CN17.P$1 (1), CN17.P$2 (2), CN17.P$3 (3), CN17.P$4 (4), CN17.P$5 (5), CN17.P$6 (6), CN17.P$7 (7), CN17.P$8 (8), CN17.P$9 (9), CN17.P$10 (10), CN17.P$11 (11), D232.C, Q8.C, R24.2
ROW8: CN18.P$1 (1), CN18.P$2 (2), CN18.P$3 (3), CN18.P$4 (4), CN18.P$5 (5), CN18.P$6 (6), CN18.P$7 (7), CN18.P$8 (8), CN18.P$9 (9), CN18.P$10 (10), CN18.P$11 (11), D235.C, Q9.C, R25.2
ROW9: CN21.P$1 (1), CN21.P$2 (2), CN21.P$3 (3), CN21.P$4 (4), CN21.P$5 (5), CN21.P$6 (6), CN21.P$7 (7), CN21.P$8 (8), CN21.P$9 (9), CN21.P$10 (10), CN21.P$11 (11), D238.C, Q10.C, R26.2
ROW10: CN23.P$1 (1), CN23.P$2 (2), CN23.P$3 (3), CN23.P$4 (4), CN23.P$5 (5), CN23.P$6 (6), CN23.P$7 (7), CN23.P$8 (8), CN23.P$9 (9), CN23.P$10 (10), CN23.P$11 (11), D241.C, Q11.C, R27.2
ROW11: CN25.P$1 (1), CN25.P$2 (2), CN25.P$3 (3), CN25.P$4 (4), CN25.P$5 (5), CN25.P$6 (6), CN25.P$7 (7), CN25.P$8 (8), CN25.P$9 (9), CN25.P$10 (10), CN25.P$11 (11), D244.C, Q12.C, R28.2
ROW12: CN27.P$1 (1), CN27.P$2 (2), CN27.P$3 (3), CN27.P$4 (4), CN27.P$5 (5), CN27.P$6 (6), CN27.P$7 (7), CN27.P$8 (8), CN27.P$9 (9), CN27.P$10 (10), CN27.P$11 (11), D247.C, Q13.C, R29.2
ROW13: CN29.P$1 (1), CN29.P$2 (2), CN29.P$3 (3), CN29.P$4 (4), CN29.P$5 (5), CN29.P$6 (6), CN29.P$7 (7), CN29.P$8 (8), CN29.P$9 (9), CN29.P$10 (10), CN29.P$11 (11), D250.C, Q14.C, R30.2
ROW14: CN31.P$1 (1), CN31.P$2 (2), CN31.P$3 (3), CN31.P$4 (4), CN31.P$5 (5), CN31.P$6 (6), CN31.P$7 (7), CN31.P$8 (8), CN31.P$9 (9), CN31.P$10 (10), CN31.P$11 (11), D253.C, Q15.C, R31.2
ROW15: CN33.P$1 (1), CN33.P$2 (2), CN33.P$3 (3), CN33.P$4 (4), CN33.P$5 (5), CN33.P$6 (6), CN33.P$7 (7), CN33.P$8 (8), CN33.P$9 (9), CN33.P$10 (10), CN33.P$11 (11), D256.C, Q16.C, R32.2
SEL0: CN35.P23@1 (23), CN35.P23@2 (23), D179.C
SEL1: CN35.P24@1 (24), CN35.P24@2 (24), D180.C
SEL2: CN35.P25@1 (25), CN35.P25@2 (25), D198.C
SEL3: CN35.P26@1 (26), CN35.P26@2 (26), D199.C
SEL4: CN35.P27@1 (27), CN35.P27@2 (27), D200.C
SEL5: CN35.P28@1 (28), CN35.P28@2 (28), D201.C
SEL6: CN35.P29@1 (29), CN35.P29@2 (29), D202.C
SEL7: CN35.P30@1 (30), CN35.P30@2 (30), D203.C
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

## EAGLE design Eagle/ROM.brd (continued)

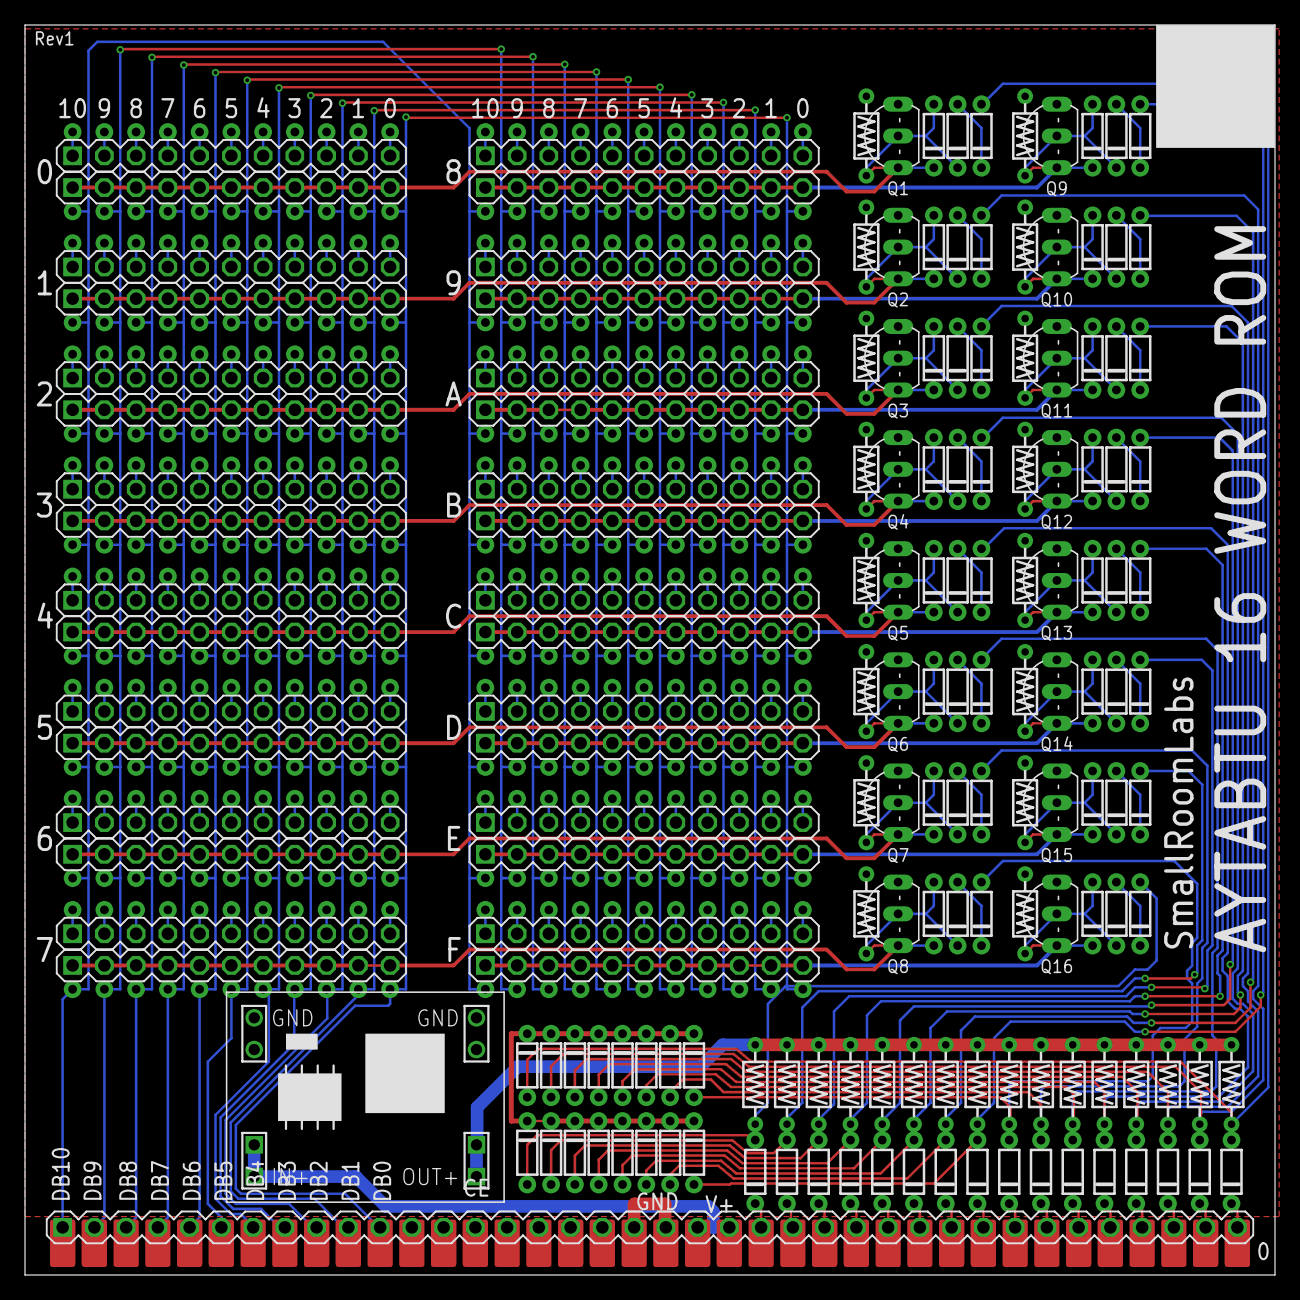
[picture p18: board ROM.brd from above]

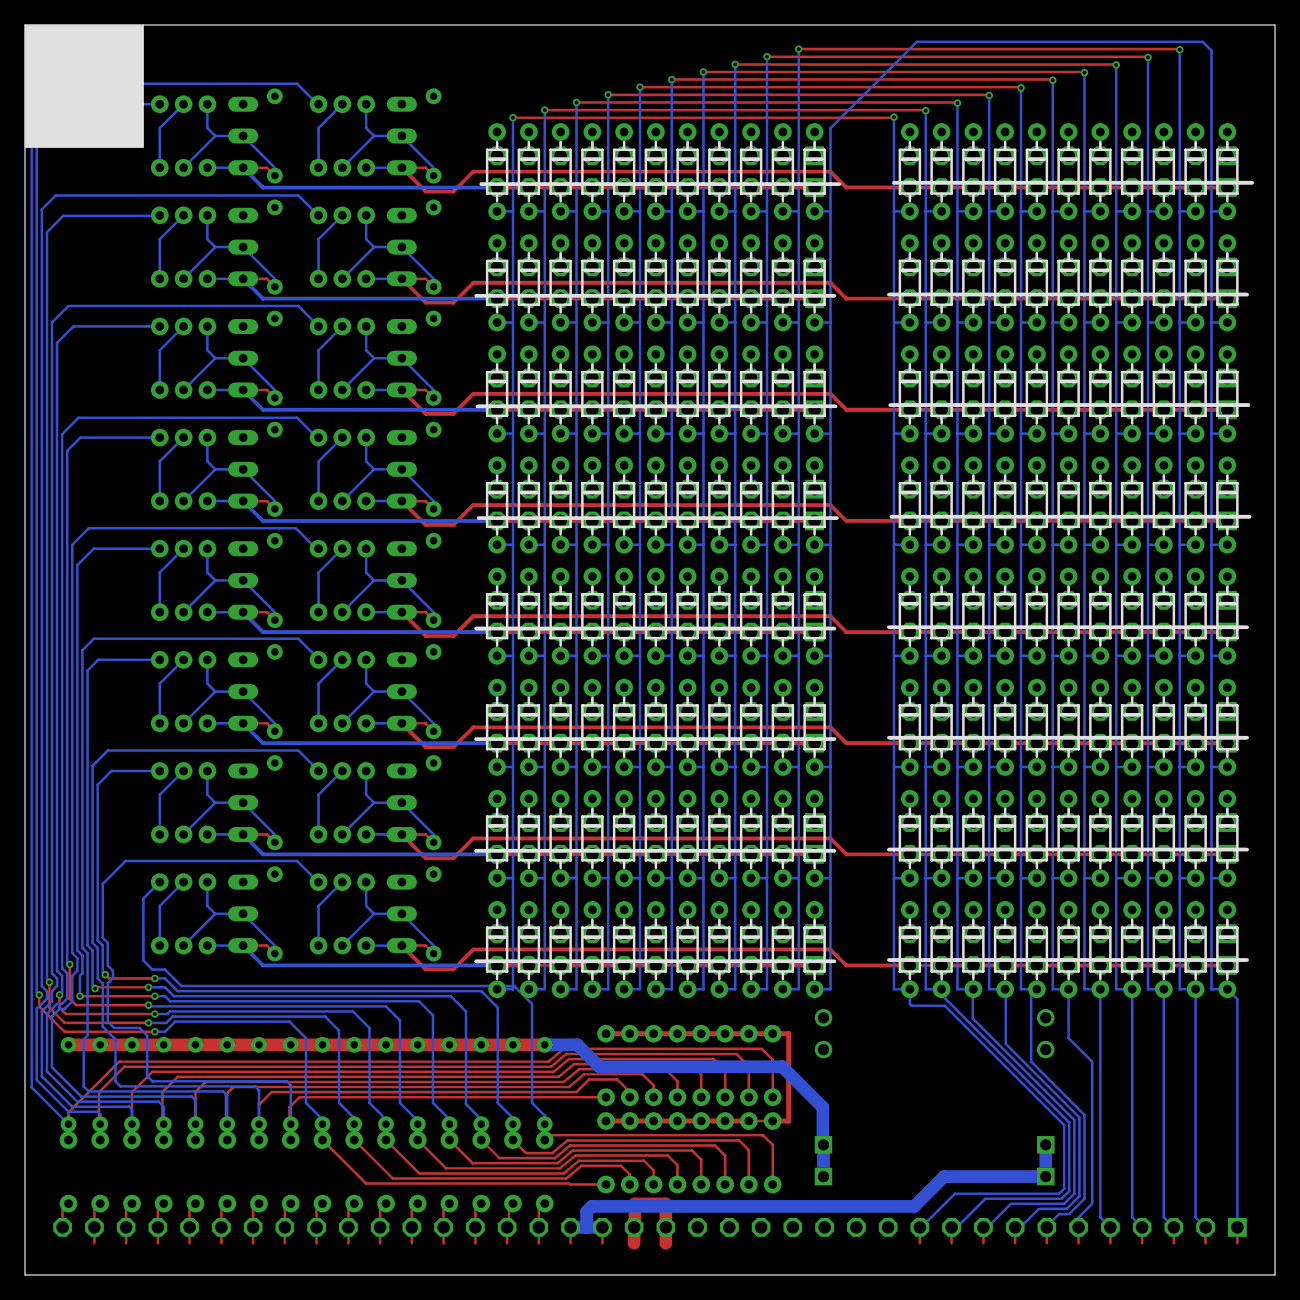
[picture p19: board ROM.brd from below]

Board: 2 copper layers, 100.0 x 100.0 mm, 338 parts (176 on the bottom side), 271 nets.

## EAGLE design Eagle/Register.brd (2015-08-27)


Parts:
C1, C2, C3, C4, C5: C0603-NPOL; C0603
D1, D2, D3, D4, D5, D7, D8, D10, D11, D12, D13, D15, D16, D17, D19, D20, D21, D23, D24, D25, D26, D28, D29, D30, D31: DIODE-SOD323; SOD323F
D6, D9, D14, D18, D22, D27: SCHOTTKYSOT323; SOT23
Q1, Q2, Q3, Q4, Q5, Q6, Q7, Q8: BC547-SOT23; SOT23
R1, R4, R6, R7, R8, R9: 470; R0805
R2, R3, R5, R10, R11, R12, R13, R14: 150; R0805
RN1: RESISTOR_ARRAY_4; RN8P-4R-CRA06S

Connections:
D0: D1.C
DIN1: D31.A
DOUT1: D27.3 (C), Q6.3 (C)
GND: C1.2, C2.2, C3.2, C4.2, C5.2, Q1.2 (E), Q2.2 (E), Q3.2 (E), Q4.2 (E), Q5.2 (E), Q6.2 (E), Q7.2 (E), Q8.2 (E)
LD: D2.C, D15.C
unnamed: D1.A, D2.A, D3.A, R1.1
unnamed: D3.C, D4.A
unnamed: D4.C, D6.1 (A), Q1.1 (B)
unnamed: D13.A, D15.A, D16.A, R6.1
unnamed: D8.A, D10.A, D11.A, R4.1
unnamed: D5.A, D16.C
unnamed: D7.A, D11.C
unnamed: D5.C, D14.1 (A), Q3.1 (B)
unnamed: D7.C, D9.1 (A), Q2.1 (B)
unnamed: D17.A, D20.A, R7.1
unnamed: D12.A, D20.C
unnamed: D12.C, D18.1 (A), Q4.1 (B)
unnamed: D21.A, D23.A, D24.A, R9.1
unnamed: D19.A, D24.C
unnamed: D19.C, D22.1 (A), Q5.1 (B)
unnamed: D26.C, Q8.3 (C), R10.1, R12.1
unnamed: D26.A, D28.A, D29.A, R8.1
unnamed: D25.A, D29.C
unnamed: D25.C, D27.1 (A), Q6.1 (B)
unnamed: Q7.3 (C), Q8.1 (B), R11.1
unnamed: Q7.1 (B), R12.2, R13.1, R14.1
unnamed: D30.A, R13.2
unnamed: D31.C, R14.2
unnamed: D10.C, D18.3 (C), D21.C, Q4.3 (C), R5.1
unnamed: D9.3 (C), D14.3 (C), D17.C, Q2.3 (C), Q3.3 (C), R3.1
unnamed: D6.3 (C), D8.C, D13.C, Q1.3 (C), R2.1
Q0: D22.3 (C), Q5.3 (C)
RD: D23.C
RD1: D28.C
RESET: D30.C
V+: C1.1, C2.1, C3.1, C4.1, C5.1, R1.2, R2.2, R3.2, R4.2, R5.2, R6.2, R7.2, R8.2, R9.2, R10.2, R11.2


Board: 2 copper layers, 59 parts (0 on the bottom side), 31 nets.

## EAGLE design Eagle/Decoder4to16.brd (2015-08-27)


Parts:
CN1: HD38-HP; HD38-HOLEPAD
D1, D2, D3, D5, D6, D7, D9, D10, D11, D13, D14, D15, D17, D18, D19, D21, D22, D23, D25, D26, D27, D29, D30, D31, D32, D33, D34, D35, D36, D37, D38, D39, D40, D41, D42, D43, D44, D45, D46, D47, D48, D49, D50, D51, D52, D53, D54, D55, D56, D57, D58, D59, D60, D61, D62, D63, D64, D65, D66, D67, D68, D69, D70, D71, D72, D73, D74, D75, D76, D77, D78, D79, D80, D81, D82, D83, D84, D85, D86, D87, D88, D89, D90, D91, D92, D93, D94, D95, D96, D97, D98, D99, D100, D101, D102, D103, D104, D105, D106, D107, D108, D109, D110, D111, D113, D114, D115, D117, D118, D119, D120, D121, D123, D124: DIODE-SOD323; SOD323F
D4, D8, D12, D16, D20, D24, D28, D112, D116, D122: SCHOTTKYSOT323; SOT23
Q1, Q2, Q3, Q4, Q5, Q6, Q7, Q8, Q9, Q10: BC547-SOT23; SOT23
R1, R4, R6, R8, R10, R12, R14, R16, R18, R20: 470; R0805
R2, R3, R5, R7, R9, R11, R13, R15, R17, R19: 150; R0805
R22, R23, R24, R25, R26, R27, R28, R29, R30, R31, R32, R33, R34, R35, R36, R37: R-0805; R0805
VR1: SMPS; BUCK1722

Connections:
!A0: D4.3 (C), D7.C, D30.C, D40.C, D50.C, D60.C, D70.C, D80.C, D90.C, D100.C, Q1.3 (C), R2.1
!A1: D12.3 (C), D15.C, D31.C, D36.C, D51.C, D56.C, D71.C, D76.C, D91.C, D96.C, Q3.3 (C), R5.1
!A2: D20.3 (C), D23.C, D32.C, D37.C, D42.C, D47.C, D72.C, D77.C, D82.C, D87.C, Q5.3 (C), R9.1
!A3: D28.3 (C), D33.C, D38.C, D43.C, D48.C, D53.C, D58.C, D63.C, D68.C, D111.C, Q7.3 (C), R13.1
!E: D116.3 (C), D121.C, Q9.3 (C), R17.1
!E1: CN1.P8@1 (8), CN1.P8@2 (8), D123.C
!E2: CN1.P9@1 (9), CN1.P9@2 (9), D124.C
A0: D8.3 (C), D35.C, D45.C, D55.C, D65.C, D75.C, D85.C, D95.C, D105.C, Q2.3 (C), R3.1
A0IN: CN1.P1@1 (1), CN1.P1@2 (1), D1.C
A1: D16.3 (C), D41.C, D46.C, D61.C, D66.C, D81.C, D86.C, D101.C, D106.C, Q4.3 (C), R7.1
A1IN: CN1.P2@1 (2), CN1.P2@2 (2), D11.C
A2: D24.3 (C), D52.C, D57.C, D62.C, D67.C, D92.C, D97.C, D102.C, D107.C, Q6.3 (C), R11.1
A2IN: CN1.P3@1 (3), CN1.P3@2 (3), D19.C
A3: D73.C, D78.C, D83.C, D88.C, D93.C, D98.C, D103.C, D108.C, D112.3 (C), Q8.3 (C), R15.1
A3IN: CN1.P4@1 (4), CN1.P4@2 (4), D27.C
E: D29.C, D34.C, D39.C, D44.C, D49.C, D54.C, D59.C, D64.C, D69.C, D74.C, D79.C, D84.C, D89.C, D94.C, D99.C, D104.C, D122.3 (C), Q10.3 (C), R19.1
E0: CN1.P5@1 (5), CN1.P5@2 (5), D115.C
E1: CN1.P6@1 (6), CN1.P6@2 (6), D117.C
E2: CN1.P7@1 (7), CN1.P7@2 (7), D118.C
GND: CN1.P19@1 (19), CN1.P19@2 (19), CN1.P20@1 (20), CN1.P20@2 (20), Q1.2 (E), Q2.2 (E), Q3.2 (E), Q4.2 (E), Q5.2 (E), Q6.2 (E), Q7.2 (E), Q8.2 (E), Q9.2 (E), Q10.2 (E), VR1.GND@1 (GND), VR1.GND@2 (GND), VR1.GND@3 (GND), VR1.GND@4 (GND); also elsewhere on the board
unnamed: D1.A, D2.A, R1.1
unnamed: D3.C, D4.1 (A), Q1.1 (B)
unnamed: D2.C, D3.A
unnamed: D5.C, D8.1 (A), Q2.1 (B)
unnamed: D5.A, D6.C
unnamed: D6.A, D7.A, R4.1
unnamed: D9.C, D12.1 (A), Q3.1 (B)
unnamed: D9.A, D10.C
unnamed: D10.A, D11.A, R6.1
unnamed: D13.C, D16.1 (A), Q4.1 (B)
unnamed: D13.A, D14.C
unnamed: D14.A, D15.A, R8.1
unnamed: D17.C, D20.1 (A), Q5.1 (B)
unnamed: D17.A, D18.C
unnamed: D18.A, D19.A, R10.1
unnamed: D21.C, D24.1 (A), Q6.1 (B)
unnamed: D21.A, D22.C
unnamed: D22.A, D23.A, R12.1
unnamed: D25.C, D28.1 (A), Q7.1 (B)
unnamed: D25.A, D26.C
unnamed: D26.A, D27.A, R14.1
unnamed: D109.C, D112.1 (A), Q8.1 (B)
unnamed: D109.A, D110.C
unnamed: D110.A, D111.A, R16.1
unnamed: D113.C, D116.1 (A), Q9.1 (B)
unnamed: D113.A, D114.C
unnamed: D119.C, D122.1 (A), Q10.1 (B)
unnamed: D119.A, D120.C
unnamed: D120.A, D121.A, D123.A, D124.A, R20.1
unnamed: D114.A, D115.A, D117.A, D118.A, R18.1
SEL0: CN1.P23@1 (23), CN1.P23@2 (23); also elsewhere on the board
SEL1: CN1.P24@1 (24), CN1.P24@2 (24); also elsewhere on the board
SEL2: CN1.P25@1 (25), CN1.P25@2 (25); also elsewhere on the board
SEL3: CN1.P26@1 (26), CN1.P26@2 (26); also elsewhere on the board
SEL4: CN1.P27@1 (27), CN1.P27@2 (27); also elsewhere on the board
SEL5: CN1.P28@1 (28), CN1.P28@2 (28); also elsewhere on the board
SEL6: CN1.P29@1 (29), CN1.P29@2 (29); also elsewhere on the board
SEL7: CN1.P30@1 (30), CN1.P30@2 (30); also elsewhere on the board
SEL8: CN1.P31@1 (31), CN1.P31@2 (31); also elsewhere on the board
SEL9: CN1.P32@1 (32), CN1.P32@2 (32); also elsewhere on the board
SEL10: CN1.P33@1 (33), CN1.P33@2 (33); also elsewhere on the board
SEL11: CN1.P34@1 (34), CN1.P34@2 (34); also elsewhere on the board
SEL12: CN1.P35@1 (35), CN1.P35@2 (35); also elsewhere on the board
SEL13: CN1.P36@1 (36), CN1.P36@2 (36); also elsewhere on the board
SEL14: CN1.P37@1 (37), CN1.P37@2 (37); also elsewhere on the board
SEL15: CN1.P38@1 (38), CN1.P38@2 (38); also elsewhere on the board
SUM0: D29.A, D30.A, D31.A, D32.A, D33.A, R22.1; also elsewhere on the board
SUM1: D34.A, D35.A, D36.A, D37.A, D38.A, R23.1; also elsewhere on the board
SUM2: D39.A, D40.A, D41.A, D42.A, D43.A, R24.1; also elsewhere on the board
SUM3: D44.A, D45.A, D46.A, D47.A, D48.A, R25.1; also elsewhere on the board
SUM4: D49.A, D50.A, D51.A, D52.A, D53.A, R26.1; also elsewhere on the board
SUM5: D54.A, D55.A, D56.A, D57.A, D58.A, R27.1; also elsewhere on the board
SUM6: D59.A, D60.A, D61.A, D62.A, D63.A, R28.1; also elsewhere on the board
SUM7: D64.A, D65.A, D66.A, D67.A, D68.A, R29.1; also elsewhere on the board
SUM8: D69.A, D70.A, D71.A, D72.A, D73.A, R30.1; also elsewhere on the board
SUM9: D74.A, D75.A, D76.A, D77.A, D78.A, R31.1; also elsewhere on the board
SUM10: D79.A, D80.A, D81.A, D82.A, D83.A, R32.1; also elsewhere on the board
SUM11: D84.A, D85.A, D86.A, D87.A, D88.A, R33.1; also elsewhere on the board
SUM12: D89.A, D90.A, D91.A, D92.A, D93.A, R34.1; also elsewhere on the board
SUM13: D94.A, D95.A, D96.A, D97.A, D98.A, R35.1; also elsewhere on the board
SUM14: D99.A, D100.A, D101.A, D102.A, D103.A, R36.1; also elsewhere on the board
SUM15: D104.A, D105.A, D106.A, D107.A, D108.A, R37.1; also elsewhere on the board
V+: R1.2, R2.2, R3.2, R4.2, R5.2, R6.2, R7.2, R8.2, R9.2, R10.2, R11.2, R12.2, R13.2, R14.2, R15.2, R16.2, R17.2, R18.2, R19.2, R20.2, R22.2, R23.2, R24.2, R25.2, R26.2, R27.2, R28.2, R29.2, R30.2, R31.2, R32.2, R33.2, R34.2, R35.2, R36.2, R37.2, VR1.OUT@1 (VOUT), VR1.OUT@2 (VOUT); also elsewhere on the board
VIN: CN1.P21@1 (21), CN1.P21@2 (21), CN1.P22@1 (22), CN1.P22@2 (22), VR1.IN@1 (VIN), VR1.IN@2 (VIN)


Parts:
D125, D126, D127, D128, D129, D130, D131, D132, D133, D134, D135, D136, D137, D138, D139, D140, D189, D190, D191, D192, D193, D194, D195, D196, D197, D198, D199, D200, D201, D202, D203, D204: SCHOTTKYSOT323; SOT23
D141, D142, D143, D144, D145, D146, D147, D148, D149, D150, D151, D152, D153, D154, D155, D156, D157, D158, D159, D160, D161, D162, D163, D164, D165, D166, D167, D168, D169, D170, D171, D172, D173, D174, D175, D176, D177, D178, D179, D180, D181, D182, D183, D184, D185, D186, D187, D188, D205, D206, D207, D208, D209, D210, D211, D212, D213, D214, D215, D216, D217, D218, D219, D220, D221, D222, D223, D224, D225, D226, D227, D228, D229, D230, D231, D232, D233, D234, D235, D236, D237, D238, D239, D240, D241, D242, D243, D244, D245, D246, D247, D248, D249, D250, D251, D252: DIODE-SOD323; SOD323F
Q11, Q12, Q13, Q14, Q15, Q16, Q17, Q18, Q19, Q20, Q21, Q22, Q23, Q24, Q25, Q26, Q27, Q28, Q29, Q30, Q31, Q32, Q33, Q34, Q35, Q36, Q37, Q38, Q39, Q40, Q41, Q42: BC547-SOT23; SOT23
R21, R38, R39, R40, R41, R42, R43, R44, R45, R46, R47, R48, R49, R50, R51, R52, R53, R54, R55, R56, R57, R58, R59, R60, R61, R62, R63, R64, R65, R66, R67, R68, R69, R70, R71, R72, R73, R74, R75, R76, R77, R78, R79, R80, R81, R82, R83, R84, R85, R86, R87, R88, R89, R90, R91, R92, R93, R94, R95, R96, R97, R98, R99, R100: R-0805; R0805

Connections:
GND: Q11.2 (E), Q12.2 (E), Q13.2 (E), Q14.2 (E), Q15.2 (E), Q16.2 (E), Q17.2 (E), Q18.2 (E), Q19.2 (E), Q20.2 (E), Q21.2 (E), Q22.2 (E), Q23.2 (E), Q24.2 (E), Q25.2 (E), Q26.2 (E), Q27.2 (E), Q28.2 (E), Q29.2 (E), Q30.2 (E), Q31.2 (E), Q32.2 (E), Q33.2 (E), Q34.2 (E), Q35.2 (E), Q36.2 (E), Q37.2 (E), Q38.2 (E), Q39.2 (E), Q40.2 (E), Q41.2 (E), Q42.2 (E); also elsewhere on the board
unnamed: D125.1 (A), D157.C, Q11.1 (B)
unnamed: D126.1 (A), D159.C, Q12.1 (B)
unnamed: D127.1 (A), D161.C, Q13.1 (B)
unnamed: D128.1 (A), D163.C, Q14.1 (B)
unnamed: D129.1 (A), D165.C, Q15.1 (B)
unnamed: D130.1 (A), D167.C, Q16.1 (B)
unnamed: D131.1 (A), D169.C, Q17.1 (B)
unnamed: D132.1 (A), D171.C, Q18.1 (B)
unnamed: D140.1 (A), D141.C, Q19.1 (B)
unnamed: D139.1 (A), D143.C, Q20.1 (B)
unnamed: D138.1 (A), D145.C, Q21.1 (B)
unnamed: D137.1 (A), D147.C, Q22.1 (B)
unnamed: D136.1 (A), D149.C, Q23.1 (B)
unnamed: D135.1 (A), D151.C, Q24.1 (B)
unnamed: D134.1 (A), D153.C, Q25.1 (B)
unnamed: D133.1 (A), D155.C, Q26.1 (B)
unnamed: D141.A, D142.C
unnamed: D143.A, D144.C
unnamed: D145.A, D146.C
unnamed: D147.A, D148.C
unnamed: D149.A, D150.C
unnamed: D151.A, D152.C
unnamed: D153.A, D154.C
unnamed: D155.A, D156.C
unnamed: D157.A, D158.C
unnamed: D159.A, D160.C
unnamed: D161.A, D162.C
unnamed: D163.A, D164.C
unnamed: D165.A, D166.C
unnamed: D167.A, D168.C
unnamed: D169.A, D170.C
unnamed: D171.A, D172.C
unnamed: D158.A, D173.A, R53.2
unnamed: D160.A, D174.A, R54.2
unnamed: D162.A, D175.A, R55.2
unnamed: D164.A, D176.A, R56.2
unnamed: D166.A, D177.A, R57.2
unnamed: D168.A, D178.A, R58.2
unnamed: D170.A, D179.A, R59.2
unnamed: D172.A, D180.A, R60.2
unnamed: D156.A, D181.A, R67.1
unnamed: D154.A, D182.A, R66.1
unnamed: D152.A, D183.A, R65.1
unnamed: D150.A, D184.A, R64.1
unnamed: D148.A, D185.A, R63.1
unnamed: D146.A, D186.A, R62.1
unnamed: D144.A, D187.A, R61.1
unnamed: D142.A, D188.A, R68.1
unnamed: D189.1 (A), D221.C, Q27.1 (B)
unnamed: D190.1 (A), D223.C, Q28.1 (B)
unnamed: D191.1 (A), D225.C, Q29.1 (B)
unnamed: D192.1 (A), D227.C, Q30.1 (B)
unnamed: D193.1 (A), D229.C, Q31.1 (B)
unnamed: D194.1 (A), D231.C, Q32.1 (B)
unnamed: D195.1 (A), D233.C, Q33.1 (B)
unnamed: D196.1 (A), D235.C, Q34.1 (B)
unnamed: D204.1 (A), D205.C, Q35.1 (B)
unnamed: D203.1 (A), D207.C, Q36.1 (B)
unnamed: D202.1 (A), D209.C, Q37.1 (B)
unnamed: D201.1 (A), D211.C, Q38.1 (B)
unnamed: D200.1 (A), D213.C, Q39.1 (B)
unnamed: D199.1 (A), D215.C, Q40.1 (B)
unnamed: D198.1 (A), D217.C, Q41.1 (B)
unnamed: D197.1 (A), D219.C, Q42.1 (B)
unnamed: D205.A, D206.C
unnamed: D207.A, D208.C
unnamed: D209.A, D210.C
unnamed: D211.A, D212.C
unnamed: D213.A, D214.C
unnamed: D215.A, D216.C
unnamed: D217.A, D218.C
unnamed: D219.A, D220.C
unnamed: D221.A, D222.C
unnamed: D223.A, D224.C
unnamed: D225.A, D226.C
unnamed: D227.A, D228.C
unnamed: D229.A, D230.C
unnamed: D231.A, D232.C
unnamed: D233.A, D234.C
unnamed: D235.A, D236.C
unnamed: D222.A, D237.A, R85.2
unnamed: D224.A, D238.A, R86.2
unnamed: D226.A, D239.A, R87.2
unnamed: D228.A, D240.A, R88.2
unnamed: D230.A, D241.A, R89.2
unnamed: D232.A, D242.A, R90.2
unnamed: D234.A, D243.A, R91.2
unnamed: D236.A, D244.A, R92.2
unnamed: D220.A, D245.A, R99.1
unnamed: D218.A, D246.A, R98.1
unnamed: D216.A, D247.A, R97.1
unnamed: D214.A, D248.A, R96.1
unnamed: D212.A, D249.A, R95.1
unnamed: D210.A, D250.A, R94.1
unnamed: D208.A, D251.A, R93.1
unnamed: D206.A, D252.A, R100.1
SEL0: D140.3 (C), Q19.3 (C), R45.1; also elsewhere on the board
SEL1: D139.3 (C), Q20.3 (C), R46.1; also elsewhere on the board
SEL2: D138.3 (C), Q21.3 (C), R47.1; also elsewhere on the board
SEL3: D137.3 (C), Q22.3 (C), R48.1; also elsewhere on the board
SEL4: D136.3 (C), Q23.3 (C), R49.1; also elsewhere on the board
SEL5: D135.3 (C), Q24.3 (C), R50.1; also elsewhere on the board
SEL6: D134.3 (C), Q25.3 (C), R51.1; also elsewhere on the board
SEL7: D133.3 (C), Q26.3 (C), R52.1; also elsewhere on the board
SEL8: D132.3 (C), Q18.3 (C), R44.1; also elsewhere on the board
SEL9: D131.3 (C), Q17.3 (C), R43.1; also elsewhere on the board
SEL10: D130.3 (C), Q16.3 (C), R42.1; also elsewhere on the board
SEL11: D129.3 (C), Q15.3 (C), R41.1; also elsewhere on the board
SEL12: D128.3 (C), Q14.3 (C), R40.1; also elsewhere on the board
SEL13: D127.3 (C), Q13.3 (C), R39.1; also elsewhere on the board
SEL14: D126.3 (C), Q12.3 (C), R38.1; also elsewhere on the board
SEL15: D125.3 (C), Q11.3 (C), R21.1; also elsewhere on the board
SUM0: D252.C; also elsewhere on the board
SUM1: D251.C; also elsewhere on the board
SUM2: D250.C; also elsewhere on the board
SUM3: D249.C; also elsewhere on the board
SUM4: D248.C; also elsewhere on the board
SUM5: D247.C; also elsewhere on the board
SUM6: D246.C; also elsewhere on the board
SUM7: D245.C; also elsewhere on the board
SUM8: D244.C; also elsewhere on the board
SUM9: D243.C; also elsewhere on the board
SUM10: D242.C; also elsewhere on the board
SUM11: D241.C; also elsewhere on the board
SUM12: D240.C; also elsewhere on the board
SUM13: D239.C; also elsewhere on the board
SUM14: D238.C; also elsewhere on the board
SUM15: D237.C; also elsewhere on the board
V+: R21.2, R38.2, R39.2, R40.2, R41.2, R42.2, R43.2, R44.2, R45.2, R46.2, R47.2, R48.2, R49.2, R50.2, R51.2, R52.2, R53.1, R54.1, R55.1, R56.1, R57.1, R58.1, R59.1, R60.1, R61.2, R62.2, R63.2, R64.2, R65.2, R66.2, R67.2, R68.2, R69.2, R70.2, R71.2, R72.2, R73.2, R74.2, R75.2, R76.2, R77.2, R78.2, R79.2, R80.2, R81.2, R82.2, R83.2, R84.2, R85.1, R86.1, R87.1, R88.1, R89.1, R90.1, R91.1, R92.1, R93.2, R94.2, R95.2, R96.2, R97.2, R98.2, R99.2, R100.2; also elsewhere on the board
Z0: D188.C, D204.3 (C), Q35.3 (C), R77.1
Z1: D187.C, D203.3 (C), Q36.3 (C), R78.1
Z2: D186.C, D202.3 (C), Q37.3 (C), R79.1
Z3: D185.C, D201.3 (C), Q38.3 (C), R80.1
Z4: D184.C, D200.3 (C), Q39.3 (C), R81.1
Z5: D183.C, D199.3 (C), Q40.3 (C), R82.1
Z6: D182.C, D198.3 (C), Q41.3 (C), R83.1
Z7: D181.C, D197.3 (C), Q42.3 (C), R84.1
Z8: D180.C, D196.3 (C), Q34.3 (C), R76.1
Z9: D179.C, D195.3 (C), Q33.3 (C), R75.1
Z10: D178.C, D194.3 (C), Q32.3 (C), R74.1
Z11: D177.C, D193.3 (C), Q31.3 (C), R73.1
Z12: D176.C, D192.3 (C), Q30.3 (C), R72.1
Z13: D175.C, D191.3 (C), Q29.3 (C), R71.1
Z14: D174.C, D190.3 (C), Q28.3 (C), R70.1
Z15: D173.C, D189.3 (C), Q27.3 (C), R69.1


Board: 2 copper layers, 100.0 x 100.0 mm, 396 parts (0 on the bottom side), 196 nets.

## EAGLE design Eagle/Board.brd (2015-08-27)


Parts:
CN1: HD16
CN2: HD15
U$1: HD5CN; HD5

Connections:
CS: U$1.P$1 (1)
GND: U$1.P$2 (2), U$1.P$3 (3); also elsewhere on the board
unnamed: U$1.P$4 (4), U$1.P$5 (5)
OUT0: CN2.P$1 (1)
OUT1: CN2.P$2 (2)
OUT2: CN2.P$3 (3)
OUT3: CN2.P$4 (4)
OUT4: CN2.P$5 (5)
OUT5: CN2.P$6 (6)
OUT6: CN2.P$7 (7)
OUT7: CN2.P$8 (8)
OUT8: CN2.P$9 (9)
OUT9: CN2.P$10 (10)
OUT10: CN2.P$11 (11)
OUT11: CN2.P$12 (12)
OUT12: CN2.P$13 (13)
OUT13: CN2.P$14 (14)
OUT14: CN2.P$15 (15)
SEL0: CN1.P$1 (1)
SEL1: CN1.P$2 (2)
SEL2: CN1.P$3 (3)
SEL3: CN1.P$4 (4)
SEL4: CN1.P$5 (5)
SEL5: CN1.P$6 (6)
SEL6: CN1.P$7 (7)
SEL7: CN1.P$8 (8)
SEL8: CN1.P$9 (9)
SEL9: CN1.P$10 (10)
SEL10: CN1.P$11 (11)
SEL11: CN1.P$12 (12)
SEL12: CN1.P$13 (13)
SEL13: CN1.P$14 (14)
SEL14: CN1.P$15 (15)
SEL15: CN1.P$16 (16)


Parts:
CN0: HD11
CN34: HD4

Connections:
!AE1: CN0.P$5 (5)
!BE1: CN0.P$10 (10)
A0IN: CN0.P$1 (1); also elsewhere on the board
A1IN: CN0.P$2 (2); also elsewhere on the board
A2IN: CN0.P$3 (3); also elsewhere on the board
AE0: CN0.P$4 (4)
B0IN: CN0.P$6 (6)
B1IN: CN0.P$7 (7)
B2IN: CN0.P$8 (8)
BE0: CN0.P$9 (9)
GND: CN34.P$1 (1), CN34.P$2 (2); also elsewhere on the board
unnamed: CN34.P$3 (3), CN34.P$4 (4)


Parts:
CN19: HD16

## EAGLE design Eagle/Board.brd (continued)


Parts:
CN3: HD11
CN5: HD4

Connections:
!E1: CN3.P$8 (8)
!E2: CN3.P$9 (9)
A0IN: CN3.P$1 (1); also elsewhere on the board
A1IN: CN3.P$2 (2); also elsewhere on the board
A2IN: CN3.P$3 (3); also elsewhere on the board
A3IN: CN3.P$4 (4)
E0: CN3.P$5 (5)
E1: CN3.P$6 (6)
E2: CN3.P$7 (7)
GND: CN5.P$1 (1), CN5.P$2 (2); also elsewhere on the board
unnamed: CN5.P$3 (3), CN5.P$4 (4)


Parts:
CN4: HD16


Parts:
CN8: HD11
CN41: HD16
CN42: HD4

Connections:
DB0: CN8.P$1 (1)
DB1: CN8.P$2 (2)
DB2: CN8.P$3 (3)
DB3: CN8.P$4 (4)
DB4: CN8.P$5 (5)
DB5: CN8.P$6 (6)
DB6: CN8.P$7 (7)
DB7: CN8.P$8 (8)
DB8: CN8.P$9 (9)
DB9: CN8.P$10 (10)
DB10: CN8.P$11 (11)
GND: CN42.P$1 (1), CN42.P$2 (2); also elsewhere on the board
SEL16: CN41.P$1 (1)
SEL17: CN41.P$2 (2)
SEL18: CN41.P$3 (3)
SEL19: CN41.P$4 (4)
SEL20: CN41.P$5 (5)
SEL21: CN41.P$6 (6)
SEL22: CN41.P$7 (7)
SEL23: CN41.P$8 (8)
SEL24: CN41.P$9 (9)
SEL25: CN41.P$10 (10)
SEL26: CN41.P$11 (11)
SEL27: CN41.P$12 (12)
SEL28: CN41.P$13 (13)
SEL29: CN41.P$16 (16)
SEL30: CN41.P$15 (15)
SEL31: CN41.P$14 (14)
V+: CN42.P$3 (3); also elsewhere on the board


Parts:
CN6: HD12
CN7: HD38-HP; HD38-HOLEPAD
U$2: HD5CN; HD5

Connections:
!BCLR: CN6.P$6 (6)
!BSET: CN6.P$7 (7)
!F2: CN6.P$8 (8)
A: U$2.P$1 (1)
B: U$2.P$2 (2)
BINV: CN6.P$5 (5)
CIN: U$2.P$4 (4)
COUT: U$2.P$5 (5)
ENA: CN6.P$1 (1)
F1: CN6.P$4 (4)
F2: CN6.P$2 (2)
GND: CN6.P$11 (11), CN6.P$12 (12); also elsewhere on the board
MODE: CN6.P$3 (3)
RES: U$2.P$3 (3)
V+: CN6.P$9 (9), CN6.P$10 (10); also elsewhere on the board

Board: 2 copper layers, 15 parts (0 on the bottom side), 8 nets, no tracks yet.

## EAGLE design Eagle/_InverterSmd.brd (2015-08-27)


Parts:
D1, D2, D3, D4, D5: DIODE-SOD323; SOD323F
D6: SCHOTTKYSOT323; SOT23
Q1: BC547-SOT23; SOT23
R1: 470; R0805
R2: 150; R0805

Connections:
A: D1.C
B: D2.C
C: D3.C
GND: Q1.2 (E)
unnamed: D1.A, D2.A, D3.A, D4.A, R1.1
unnamed: D5.C, D6.1 (A), Q1.1 (B)
unnamed: D4.C, D5.A
Q: D6.3 (C), Q1.3 (C), R2.1
V+: R1.2, R2.2


Board: 2 copper layers, 9 parts (0 on the bottom side), 5 nets.

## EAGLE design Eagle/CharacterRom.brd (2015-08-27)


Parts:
CN3: HD38-HP; HD38-HOLEPAD
D1, D2, D3, D4, D5, D6, D7, D8, D9, D10, D11, D12, D13, D14, D15, D16, D17, D18, D19, D20, D21, D22, D23, D24, D25, D26, D27, D28, D29, D30, D31, D32, D33, D34, D35, D36, D37, D38, D39, D40, D41, D42, D43, D44, D45, D46, D47, D48, D49, D50, D51, D52, D53, D54, D55, D56, D57, D58, D59, D60, D61, D62, D63, D64, D65, D66, D67, D68, D69, D70, D71, D72, D73, D74, D75, D76, D77, D78, D79, D80, D81, D82, D83, D84, D85, D86, D87, D88, D89, D90, D91, D92, D93, D94, D95, D96, D97, D98, D99, D100, D101, D102, D103, D104, D105, D106, D107, D108, D109, D110, D111, D112, D113, D114, D115, D116, D117, D118, D119, D120, D121, D122, D123, D124, D125, D126, D127, D128, D129, D130, D131, D132, D133, D134, D135, D136, D137, D138, D139, D140, D141, D142, D143, D144, D145, D146, D147, D148, D149, D150, D151, D152, D153, D154, D155, D156, D157, D158, D159, D160, D161, D162, D163, D164, D165, D166, D167, D168, D169, D170, D171, D172, D173, D174, D175, D176, D177, D178, D179, D180, D181, D182, D183, D184, D185, D186, D187, D188, D189, D190, D191, D192, D193, D194, D195, D196, D197, D198, D199, D200, D201, D202, D203, D204, D205, D206, D207, D208, D209, D210, D211, D212, D213, D214, D215, D216, D217, D218, D219, D220, D221, D222, D223, D224, D225, D226, D227, D228, D229, D230, D231, D232, D233, D234, D235, D236, D237, D238, D239, D240: DIODESOD-323F; SOD-323F
VR1: SMPS; BUCK1722

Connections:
CH0: D1.C, D2.C, D3.C, D4.C, D5.C, D6.C, D7.C, D8.C, D9.C, D10.C, D11.C, D12.C, D13.C, D14.C, D15.C; also elsewhere on the board
CH1: D16.C, D17.C, D18.C, D19.C, D20.C, D21.C, D22.C, D23.C, D24.C, D25.C, D26.C, D27.C, D28.C, D29.C, D30.C; also elsewhere on the board
CH2: D31.C, D32.C, D33.C, D34.C, D35.C, D36.C, D37.C, D38.C, D39.C, D40.C, D41.C, D42.C, D43.C, D44.C, D45.C; also elsewhere on the board
CH3: D46.C, D47.C, D48.C, D49.C, D50.C, D51.C, D52.C, D53.C, D54.C, D55.C, D56.C, D57.C, D58.C, D59.C, D60.C; also elsewhere on the board
CH4: D61.C, D62.C, D63.C, D64.C, D65.C, D66.C, D67.C, D68.C, D69.C, D70.C, D71.C, D72.C, D73.C, D74.C, D75.C; also elsewhere on the board
CH5: D76.C, D77.C, D78.C, D79.C, D80.C, D81.C, D82.C, D83.C, D84.C, D85.C, D86.C, D87.C, D88.C, D89.C, D90.C; also elsewhere on the board
CH6: D91.C, D92.C, D93.C, D94.C, D95.C, D96.C, D97.C, D98.C, D99.C, D100.C, D101.C, D102.C, D103.C, D104.C, D105.C; also elsewhere on the board
CH7: D106.C, D107.C, D108.C, D109.C, D110.C, D111.C, D112.C, D113.C, D114.C, D115.C, D116.C, D117.C, D118.C, D119.C, D120.C; also elsewhere on the board
CH8: D121.C, D122.C, D123.C, D124.C, D125.C, D126.C, D127.C, D128.C, D129.C, D130.C, D131.C, D132.C, D133.C, D134.C, D135.C; also elsewhere on the board
CH9: D136.C, D137.C, D138.C, D139.C, D140.C, D141.C, D142.C, D143.C, D144.C, D145.C, D146.C, D147.C, D148.C, D149.C, D150.C; also elsewhere on the board
CH10: D151.C, D152.C, D153.C, D154.C, D155.C, D156.C, D157.C, D158.C, D159.C, D160.C, D161.C, D162.C, D163.C, D164.C, D165.C; also elsewhere on the board
CH11: D166.C, D167.C, D168.C, D169.C, D170.C, D171.C, D172.C, D173.C, D174.C, D175.C, D176.C, D177.C, D178.C, D179.C, D180.C; also elsewhere on the board
CH12: D181.C, D182.C, D183.C, D184.C, D185.C, D186.C, D187.C, D188.C, D189.C, D190.C, D191.C, D192.C, D193.C, D194.C, D195.C; also elsewhere on the board
CH13: D196.C, D197.C, D198.C, D199.C, D200.C, D201.C, D202.C, D203.C, D204.C, D205.C, D206.C, D207.C, D208.C, D209.C, D210.C; also elsewhere on the board
CH14: D211.C, D212.C, D213.C, D214.C, D215.C, D216.C, D217.C, D218.C, D219.C, D220.C, D221.C, D222.C, D223.C, D224.C, D225.C; also elsewhere on the board
CH15: D226.C, D227.C, D228.C, D229.C, D230.C, D231.C, D232.C, D233.C, D234.C, D235.C, D236.C, D237.C, D238.C, D239.C, D240.C; also elsewhere on the board
CS: CN3.P18@1 (18), CN3.P18@2 (18); also elsewhere on the board
GND: CN3.P19@1 (19), CN3.P19@2 (19), CN3.P20@1 (20), CN3.P20@2 (20), VR1.GND@1 (GND), VR1.GND@2 (GND), VR1.GND@3 (GND), VR1.GND@4 (GND); also elsewhere on the board
OUT0: CN3.P23@1 (23), CN3.P23@2 (23), D1.A, D17.A, D32.A, D47.A, D62.A, D77.A, D92.A, D107.A, D122.A, D137.A, D152.A, D167.A, D182.A, D197.A, D212.A, D227.A
OUT1: CN3.P24@1 (24), CN3.P24@2 (24), D2.A, D18.A, D33.A, D48.A, D63.A, D78.A, D93.A, D108.A, D123.A, D138.A, D153.A, D168.A, D183.A, D198.A, D213.A, D228.A
OUT2: CN3.P25@1 (25), CN3.P25@2 (25), D3.A, D16.A, D31.A, D46.A, D61.A, D76.A, D91.A, D106.A, D121.A, D136.A, D151.A, D166.A, D181.A, D196.A, D211.A, D226.A
OUT3: CN3.P26@1 (26), CN3.P26@2 (26), D4.A, D19.A, D34.A, D49.A, D64.A, D79.A, D94.A, D109.A, D124.A, D139.A, D154.A, D169.A, D184.A, D199.A, D214.A, D229.A
OUT4: CN3.P27@1 (27), CN3.P27@2 (27), D5.A, D20.A, D35.A, D50.A, D65.A, D80.A, D95.A, D110.A, D125.A, D140.A, D155.A, D170.A, D185.A, D200.A, D215.A, D230.A
OUT5: CN3.P28@1 (28), CN3.P28@2 (28), D6.A, D21.A, D36.A, D51.A, D66.A, D81.A, D96.A, D111.A, D126.A, D141.A, D156.A, D171.A, D186.A, D201.A, D216.A, D231.A
OUT6: CN3.P29@1 (29), CN3.P29@2 (29), D7.A, D22.A, D37.A, D52.A, D67.A, D82.A, D97.A, D112.A, D127.A, D142.A, D157.A, D172.A, D187.A, D202.A, D217.A, D232.A
OUT7: CN3.P30@1 (30), CN3.P30@2 (30), D8.A, D23.A, D38.A, D53.A, D68.A, D83.A, D98.A, D113.A, D128.A, D143.A, D158.A, D173.A, D188.A, D203.A, D218.A, D233.A
OUT8: CN3.P31@1 (31), CN3.P31@2 (31), D9.A, D24.A, D39.A, D54.A, D69.A, D84.A, D99.A, D114.A, D129.A, D144.A, D159.A, D174.A, D189.A, D204.A, D219.A, D234.A
OUT9: CN3.P32@1 (32), CN3.P32@2 (32), D10.A, D25.A, D40.A, D55.A, D70.A, D85.A, D100.A, D115.A, D130.A, D145.A, D160.A, D175.A, D190.A, D205.A, D220.A, D235.A
OUT10: CN3.P33@1 (33), CN3.P33@2 (33), D11.A, D26.A, D41.A, D56.A, D71.A, D86.A, D101.A, D116.A, D131.A, D146.A, D161.A, D176.A, D191.A, D206.A, D221.A, D236.A
OUT11: CN3.P34@1 (34), CN3.P34@2 (34), D12.A, D27.A, D42.A, D57.A, D72.A, D87.A, D102.A, D117.A, D132.A, D147.A, D162.A, D177.A, D192.A, D207.A, D222.A, D237.A
OUT12: CN3.P35@1 (35), CN3.P35@2 (35), D13.A, D28.A, D43.A, D58.A, D73.A, D88.A, D103.A, D118.A, D133.A, D148.A, D163.A, D178.A, D193.A, D208.A, D223.A, D238.A
OUT13: CN3.P36@1 (36), CN3.P36@2 (36), D14.A, D29.A, D44.A, D59.A, D74.A, D89.A, D104.A, D119.A, D134.A, D149.A, D164.A, D179.A, D194.A, D209.A, D224.A, D239.A
OUT14: CN3.P37@1 (37), CN3.P37@2 (37), D15.A, D30.A, D45.A, D60.A, D75.A, D90.A, D105.A, D120.A, D135.A, D150.A, D165.A, D180.A, D195.A, D210.A, D225.A, D240.A
SEL0: CN3.P2@1 (2), CN3.P2@2 (2); also elsewhere on the board
SEL1: CN3.P3@1 (3), CN3.P3@2 (3); also elsewhere on the board
SEL2: CN3.P4@1 (4), CN3.P4@2 (4); also elsewhere on the board
SEL3: CN3.P5@1 (5), CN3.P5@2 (5); also elsewhere on the board
SEL4: CN3.P6@1 (6), CN3.P6@2 (6); also elsewhere on the board
SEL5: CN3.P7@1 (7), CN3.P7@2 (7); also elsewhere on the board
SEL6: CN3.P8@1 (8), CN3.P8@2 (8); also elsewhere on the board
SEL7: CN3.P9@1 (9), CN3.P9@2 (9); also elsewhere on the board
SEL8: CN3.P10@1 (10), CN3.P10@2 (10); also elsewhere on the board
SEL9: CN3.P11@1 (11), CN3.P11@2 (11); also elsewhere on the board
SEL10: CN3.P12@1 (12), CN3.P12@2 (12); also elsewhere on the board
SEL11: CN3.P13@1 (13), CN3.P13@2 (13); also elsewhere on the board
SEL12: CN3.P14@1 (14), CN3.P14@2 (14); also elsewhere on the board
SEL13: CN3.P15@1 (15), CN3.P15@2 (15); also elsewhere on the board
SEL14: CN3.P16@1 (16), CN3.P16@2 (16); also elsewhere on the board
SEL15: CN3.P17@1 (17), CN3.P17@2 (17); also elsewhere on the board
V+: VR1.OUT@1 (VOUT), VR1.OUT@2 (VOUT); also elsewhere on the board
VIN: CN3.P21@1 (21), CN3.P21@2 (21), CN3.P22@1 (22), CN3.P22@2 (22), VR1.IN@1 (VIN), VR1.IN@2 (VIN)


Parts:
C1, C2, C3, C4, C5, C6, C7, C8, C9, C10, C11, C12, C13, C14, C15, C16: C0603-NPOL; C0603
D256, D257, D258, D305, D307, D308, D309, D311, D611, D612, D613, D615, D616, D617, D618, D620, D621, D622, D623, D625, D626, D627, D628, D630, D631, D632, D633, D635, D636, D637, D638, D640, D641, D642, D643, D645, D646, D647, D648, D650, D651, D652, D653, D655, D656, D657, D658, D660, D661, D662, D663, D665, D666, D667, D668, D670, D671, D672, D673, D675, D676, D677, D678, D680: DIODE-SOD323; SOD323F
D304, D310, D614, D619, D624, D629, D634, D639, D644, D649, D654, D659, D664, D669, D674, D679: SCHOTTKYSOT323; SOT23
Q1, Q2, Q33, Q34, Q35, Q36, Q37, Q38, Q39, Q40, Q41, Q42, Q43, Q44, Q45, Q46: BC547-SOT23; SOT23
R1, R4, R37, R68, R70, R72, R74, R76, R78, R80, R82, R84, R86, R88, R90, R92: 470; R0805
R2, R3, R36, R45, R69, R71, R73, R75, R77, R79, R81, R83, R85, R87, R89, R91: 150; R0805

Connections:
CH0: D310.3 (C), Q2.3 (C), R3.1; also elsewhere on the board
CH1: D304.3 (C), Q1.3 (C), R2.1; also elsewhere on the board
CH2: D619.3 (C), Q34.3 (C), R45.1; also elsewhere on the board
CH3: D614.3 (C), Q33.3 (C), R36.1; also elsewhere on the board
CH4: D629.3 (C), Q36.3 (C), R71.1; also elsewhere on the board
CH5: D624.3 (C), Q35.3 (C), R69.1; also elsewhere on the board
CH6: D639.3 (C), Q38.3 (C), R75.1; also elsewhere on the board
CH7: D634.3 (C), Q37.3 (C), R73.1; also elsewhere on the board
CH8: D649.3 (C), Q40.3 (C), R79.1; also elsewhere on the board
CH9: D644.3 (C), Q39.3 (C), R77.1; also elsewhere on the board
CH10: D659.3 (C), Q42.3 (C), R83.1; also elsewhere on the board
CH11: D654.3 (C), Q41.3 (C), R81.1; also elsewhere on the board
CH12: D669.3 (C), Q44.3 (C), R87.1; also elsewhere on the board
CH13: D664.3 (C), Q43.3 (C), R85.1; also elsewhere on the board
CH14: D679.3 (C), Q46.3 (C), R91.1; also elsewhere on the board
CH15: D674.3 (C), Q45.3 (C), R89.1; also elsewhere on the board
CS: D305.C, D311.C, D615.C, D620.C, D625.C, D630.C, D635.C, D640.C, D645.C, D650.C, D655.C, D660.C, D665.C, D670.C, D675.C, D680.C; also elsewhere on the board
GND: C1.2, C2.2, C3.2, C4.2, C5.2, C6.2, C7.2, C8.2, C9.2, C10.2, C11.2, C12.2, C13.2, C14.2, C15.2, C16.2, Q1.2 (E), Q2.2 (E), Q33.2 (E), Q34.2 (E), Q35.2 (E), Q36.2 (E), Q37.2 (E), Q38.2 (E), Q39.2 (E), Q40.2 (E), Q41.2 (E), Q42.2 (E), Q43.2 (E), Q44.2 (E), Q45.2 (E), Q46.2 (E); also elsewhere on the board
unnamed: D256.C, D304.1 (A), Q1.1 (B)
unnamed: D256.A, D257.C
unnamed: D257.A, D258.A, D305.A, R1.1
unnamed: D307.C, D310.1 (A), Q2.1 (B)
unnamed: D307.A, D308.C
unnamed: D308.A, D309.A, D311.A, R4.1
unnamed: D611.C, D614.1 (A), Q33.1 (B)
unnamed: D611.A, D612.C
unnamed: D612.A, D613.A, D615.A, R37.1
unnamed: D616.C, D619.1 (A), Q34.1 (B)
unnamed: D616.A, D617.C
unnamed: D617.A, D618.A, D620.A, R68.1
unnamed: D621.C, D624.1 (A), Q35.1 (B)
unnamed: D621.A, D622.C
unnamed: D622.A, D623.A, D625.A, R70.1
unnamed: D626.C, D629.1 (A), Q36.1 (B)
unnamed: D626.A, D627.C
unnamed: D627.A, D628.A, D630.A, R72.1
unnamed: D631.C, D634.1 (A), Q37.1 (B)
unnamed: D631.A, D632.C
unnamed: D632.A, D633.A, D635.A, R74.1
unnamed: D636.C, D639.1 (A), Q38.1 (B)
unnamed: D636.A, D637.C
unnamed: D637.A, D638.A, D640.A, R76.1
unnamed: D641.C, D644.1 (A), Q39.1 (B)
unnamed: D641.A, D642.C
unnamed: D642.A, D643.A, D645.A, R78.1
unnamed: D646.C, D649.1 (A), Q40.1 (B)
unnamed: D646.A, D647.C
unnamed: D647.A, D648.A, D650.A, R80.1
unnamed: D651.C, D654.1 (A), Q41.1 (B)
unnamed: D651.A, D652.C
unnamed: D652.A, D653.A, D655.A, R82.1
unnamed: D656.C, D659.1 (A), Q42.1 (B)
unnamed: D656.A, D657.C
unnamed: D657.A, D658.A, D660.A, R84.1
unnamed: D661.C, D664.1 (A), Q43.1 (B)
unnamed: D661.A, D662.C
unnamed: D662.A, D663.A, D665.A, R86.1
unnamed: D666.C, D669.1 (A), Q44.1 (B)
unnamed: D666.A, D667.C
unnamed: D667.A, D668.A, D670.A, R88.1
unnamed: D671.C, D674.1 (A), Q45.1 (B)
unnamed: D671.A, D672.C
unnamed: D672.A, D673.A, D675.A, R90.1
unnamed: D676.C, D679.1 (A), Q46.1 (B)
unnamed: D676.A, D677.C
unnamed: D677.A, D678.A, D680.A, R92.1
SEL0: D309.C; also elsewhere on the board
SEL1: D258.C; also elsewhere on the board
SEL2: D618.C; also elsewhere on the board
SEL3: D613.C; also elsewhere on the board
SEL4: D628.C; also elsewhere on the board
SEL5: D623.C; also elsewhere on the board
SEL6: D638.C; also elsewhere on the board
SEL7: D633.C; also elsewhere on the board
SEL8: D648.C; also elsewhere on the board
SEL9: D643.C; also elsewhere on the board
SEL10: D658.C; also elsewhere on the board
SEL11: D653.C; also elsewhere on the board
SEL12: D668.C; also elsewhere on the board
SEL13: D663.C; also elsewhere on the board
SEL14: D678.C; also elsewhere on the board
SEL15: D673.C; also elsewhere on the board
V+: C1.1, C2.1, C3.1, C4.1, C5.1, C6.1, C7.1, C8.1, C9.1, C10.1, C11.1, C12.1, C13.1, C14.1, C15.1, C16.1, R1.2, R2.2, R3.2, R4.2, R36.2, R37.2, R45.2, R68.2, R69.2, R70.2, R71.2, R72.2, R73.2, R74.2, R75.2, R76.2, R77.2, R78.2, R79.2, R80.2, R81.2, R82.2, R83.2, R84.2, R85.2, R86.2, R87.2, R88.2, R89.2, R90.2, R91.2, R92.2; also elsewhere on the board


Board: 2 copper layers, 100.0 x 100.0 mm, 386 parts (0 on the bottom side), 99 nets.

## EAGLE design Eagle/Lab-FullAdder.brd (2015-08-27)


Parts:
CN1: HD12
D86, D87, D88, D89, D90, D92, D93, D94, D95, D96, D117, D118: DIODE-6.3; DO35-6.3
D91, D97: DIODE-7.6; DO35-7.6
LD1, LD2, LD3, LD4: LED-RA; 3MMRA
Q16, Q17, Q18, Q19, Q20: 2N3904-1; TO92BH
R27, R30, R31, R32, R33, R34, R35, R38, R39, R40, R41: R1/8-7.6MM; R0125-7.6
U$1: HD5CN; HD5
VR1: SMPS; BUCK1722

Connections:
!BCLR: CN1.P$6 (6); also elsewhere on the board
!BSET: CN1.P$7 (7); also elsewhere on the board
!F2: CN1.P$8 (8); also elsewhere on the board
A: R35.2, U$1.P$1 (1); also elsewhere on the board
B: R34.2, U$1.P$2 (2); also elsewhere on the board
BINV: CN1.P$5 (5); also elsewhere on the board
CIN: U$1.P$4 (4); also elsewhere on the board
COUT: U$1.P$5 (5); also elsewhere on the board
ENA: CN1.P$1 (1); also elsewhere on the board
F1: CN1.P$4 (4); also elsewhere on the board
F2: CN1.P$2 (2); also elsewhere on the board
GND: CN1.P$11 (11), CN1.P$12 (12), LD4.C, Q16.1 (E), Q17.1 (E), Q18.1 (E), Q19.1 (E), Q20.1 (E), VR1.GND@1 (GND), VR1.GND@2 (GND), VR1.GND@3 (GND), VR1.GND@4 (GND); also elsewhere on the board
MODE: CN1.P$3 (3); also elsewhere on the board
unnamed: LD1.A, R27.1
unnamed: LD2.A, R30.1
unnamed: LD3.A, R31.1
unnamed: LD4.A, R32.1
unnamed: LD3.C, Q18.3 (C)
unnamed: LD2.C, Q16.3 (C)
unnamed: LD1.C, Q17.3 (C)
unnamed: Q18.2 (B), R33.1
unnamed: Q16.2 (B), R34.1
unnamed: Q17.2 (B), R35.1
unnamed: D97.C, Q20.3 (C), R41.1
unnamed: D91.C, Q19.3 (C), R39.1
unnamed: D86.C, D87.C, D88.C, D89.A, D117.C, R38.1
unnamed: D89.C, D90.A
unnamed: D90.C, D91.A, Q19.2 (B)
unnamed: D92.C, D93.C, D94.C, D95.A, D118.C, R40.1
unnamed: D95.C, D96.A
unnamed: D96.C, D97.A, Q20.2 (B)
RES: R33.2, U$1.P$3 (3); also elsewhere on the board
V+: CN1.P$9 (9), CN1.P$10 (10), R27.2, R30.2, R31.2, R32.2, R38.2, R39.2, R40.2, R41.2; also elsewhere on the board
VIN: VR1.IN@1 (VIN), VR1.IN@2 (VIN)
VOUT: VR1.OUT@1 (VOUT), VR1.OUT@2 (VOUT)

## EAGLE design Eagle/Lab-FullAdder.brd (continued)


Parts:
D1, D2, D3, D4, D5, D6, D7, D8, D9, D10, D12, D13, D14, D15, D16, D18, D19, D20, D21, D22, D24, D25, D26, D27, D28, D30, D31, D32, D33, D34, D36, D37, D38, D39, D40, D43, D44, D45, D46, D47, D49, D50, D51, D52, D53, D55, D56, D57, D58, D59, D62, D63, D64, D65, D66, D68, D69, D70, D71, D72, D74, D75, D76, D77, D78, D80, D81, D82, D83, D84, D85, D98, D99, D100, D101, D102, D104, D105, D106, D107, D108, D109, D110, D111, D112, D113, D114, D115, D116, D119: DIODE-6.3; DO35-6.3
D11, D17, D23, D29, D35, D41, D42, D48, D54, D60, D61, D67, D73, D79, D103: DIODE-7.6; DO35-7.6
Q1, Q2, Q3, Q4, Q5, Q6, Q7, Q8, Q9, Q10, Q11, Q12, Q13, Q14, Q15: 2N3904-1; TO92BH
R1, R2, R3, R4, R5, R6, R7, R8, R9, R10, R11, R12, R13, R14, R15, R16, R17, R18, R19, R20, R21, R22, R23, R24, R25, R26, R28, R29, R42, R43: R1/8-7.6MM; R0125-7.6

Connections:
!BCLR: D7.A, D14.A; also elsewhere on the board
!BSET: D20.A; also elsewhere on the board
!F2: D32.A; also elsewhere on the board
A: D24.A, D30.A, D37.A; also elsewhere on the board
B: D1.A, D6.A; also elsewhere on the board
BINV: D2.A, D12.A; also elsewhere on the board
CIN: D36.A, D55.A; also elsewhere on the board
COUT: D73.C, Q13.3 (C), R18.1; also elsewhere on the board
ENA: D68.A, D98.A; also elsewhere on the board
F1: D25.A; also elsewhere on the board
F2: D63.A, D113.A; also elsewhere on the board
G1OUT: D8.A, D13.A, D41.C, Q1.3 (C), R3.1
G2OUT: D11.C, D18.A, Q2.3 (C), R5.1
G3OUT: D17.C, D19.A, Q3.3 (C), R8.1
G4OUT: D23.C, D26.A, D31.A, D45.A, Q4.3 (C), R11.1
G5OUT: D29.C, D38.A, D44.A, D70.A, Q5.3 (C), R14.1
G6OUT: D35.C, D76.A, Q6.3 (C), R17.1
G7OUT: D42.C, D50.A, Q7.3 (C), R20.1
G8OUT: D48.C, D51.A, Q8.3 (C), R23.1
G9OUT: D54.C, D57.A, D64.A, Q9.3 (C), R26.1
G10OUT: D60.C, D62.A, D69.A, D114.A, Q10.3 (C), R29.1
G11OUT: D61.C, D74.A, Q11.3 (C), R6.1
G12OUT: D67.C, D75.A, Q12.3 (C), R12.1
G14OUT: D79.C, D119.A, Q14.3 (C), R24.1
GND: Q1.1 (E), Q2.1 (E), Q3.1 (E), Q4.1 (E), Q5.1 (E), Q6.1 (E), Q7.1 (E), Q8.1 (E), Q9.1 (E), Q10.1 (E), Q11.1 (E), Q12.1 (E), Q13.1 (E), Q14.1 (E), Q15.1 (E); also elsewhere on the board
MODE: D3.A, D56.A; also elsewhere on the board
unnamed: D1.C, D2.C, D4.A, D84.C, D85.C, R1.1
unnamed: D4.C, D5.A
unnamed: D5.C, D41.A, Q1.2 (B)
unnamed: D6.C, D7.C, D8.C, D9.A, D108.C, R2.1
unnamed: D9.C, D10.A
unnamed: D10.C, D11.A, Q2.2 (B)
unnamed: D3.C, D36.C, D43.A, D113.C, D114.C, R4.1
unnamed: D12.C, D13.C, D14.C, D15.A, D105.C, R7.1
unnamed: D15.C, D16.A
unnamed: D16.C, D17.A, Q3.2 (B)
unnamed: D43.C, D49.A
unnamed: D18.C, D19.C, D20.C, D21.A, D107.C, R10.1
unnamed: D21.C, D22.A
unnamed: D22.C, D23.A, Q4.2 (B)
unnamed: D49.C, D61.A, Q11.2 (B)
unnamed: D24.C, D25.C, D26.C, D27.A, D106.C, R13.1
unnamed: D27.C, D28.A
unnamed: D28.C, D29.A, Q5.2 (B)
unnamed: D30.C, D31.C, D32.C, D33.A, D109.C, R16.1
unnamed: D33.C, D34.A
unnamed: D34.C, D35.A, Q6.2 (B)
unnamed: D98.C, D99.C, D100.C, D101.A, D119.C, R42.1
unnamed: D37.C, D38.C, D39.A, D83.C, D112.C, R19.1
unnamed: D39.C, D40.A
unnamed: D40.C, D42.A, Q7.2 (B)
unnamed: D101.C, D102.A
unnamed: D102.C, D103.A, Q15.2 (B)
unnamed: D62.C, D63.C, D64.C, D65.A, D115.C, R9.1
unnamed: D44.C, D45.C, D46.A, D81.C, D110.C, R22.1
unnamed: D46.C, D47.A
unnamed: D47.C, D48.A, Q8.2 (B)
unnamed: D65.C, D66.A
unnamed: D66.C, D67.A, Q12.2 (B)
unnamed: D50.C, D51.C, D52.A, D82.C, D111.C, R25.1
unnamed: D52.C, D53.A
unnamed: D53.C, D54.A, Q9.2 (B)
unnamed: D55.C, D56.C, D57.C, D58.A, D104.C, R28.1
unnamed: D58.C, D59.A
unnamed: D59.C, D60.A, Q10.2 (B)
unnamed: D68.C, D69.C, D70.C, D71.A, D116.C, R15.1
unnamed: D71.C, D72.A
unnamed: D72.C, D73.A, Q13.2 (B)
unnamed: D74.C, D75.C, D76.C, D77.A, D80.C, R21.1
unnamed: D77.C, D78.A
unnamed: D78.C, D79.A, Q14.2 (B)
RES: D103.C, Q15.3 (C), R43.1; also elsewhere on the board
V+: R1.2, R2.2, R3.2, R4.2, R5.2, R6.2, R7.2, R8.2, R9.2, R10.2, R11.2, R12.2, R13.2, R14.2, R15.2, R16.2, R17.2, R18.2, R19.2, R20.2, R21.2, R22.2, R23.2, R24.2, R25.2, R26.2, R28.2, R29.2, R42.2, R43.2; also elsewhere on the board


Board: 2 copper layers, 100.0 x 100.0 mm, 187 parts (0 on the bottom side), 93 nets.

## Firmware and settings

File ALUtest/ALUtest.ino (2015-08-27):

#define MODE   2
#define CI     3
#define F2     4
#define A      5
#define F1     6
#define B      7
#define BINV   8
#define BCLR_  9
#define BSET_ 10
#define F2_   11
#define ENA   12
#define RESULT A0
#define COUT   A1


void setup() {
  Serial.begin(9600); 
  while (!Serial) {
    ; // wait for serial port to connect. Needed for Leonardo only
  }
  Serial.println("AYTABTU ALU Slice tester");
  
  pinMode(MODE,OUTPUT);
  pinMode(CI,OUTPUT);
  pinMode(F2,OUTPUT);
  pinMode(A,OUTPUT);
  pinMode(F1,OUTPUT);
  pinMode(B,OUTPUT);
  pinMode(BINV,OUTPUT);
  pinMode(BCLR_,OUTPUT);
  pinMode(BSET_,OUTPUT);
  pinMode(F2_,OUTPUT);
  pinMode(ENA,OUTPUT);
  pinMode(RESULT, INPUT);
  pinMode(COUT, INPUT);

  TestXor();
  TestOr();
  TestAnd();
  TestZero();
  TestOne();
  TestNot();
  TestInc();
  TestDec();
}


char *Scan(void) {
  static char table[1000];
  table[0]=0;

  strcat(table,"AB Ci- R Co\n");
  strcat(table,"===========\n");

  digitalWrite(A,LOW); digitalWrite(B,LOW); digitalWrite(CI,LOW);
  strcat(table,"00 0 - ");
  if (digitalRead(RESULT)==HIGH) strcat(table,"1 "); else strcat(table,"0 "); 
  if (digitalRead(COUT)==HIGH) strcat(table,"1\n"); else strcat(table,"0\n"); 
  
  digitalWrite(A,HIGH); digitalWrite(B,LOW); digitalWrite(CI,LOW);
  strcat(table,"10 0 - ");
  if (digitalRead(RESULT)==HIGH) strcat(table,"1 "); else strcat(table,"0 "); 
  if (digitalRead(COUT)==HIGH) strcat(table,"1\n"); else strcat(table,"0\n"); 

  digitalWrite(A,LOW); digitalWrite(B,HIGH); digitalWrite(CI,LOW);
  strcat(table,"01 0 - ");
  if (digitalRead(RESULT)==HIGH) strcat(table,"1 "); else strcat(table,"0 "); 
  if (digitalRead(COUT)==HIGH) strcat(table,"1\n"); else strcat(table,"0\n"); 

  digitalWrite(A,HIGH); digitalWrite(B,HIGH); digitalWrite(CI,LOW);
  strcat(table,"11 0 - ");
  if (digitalRead(RESULT)==HIGH) strcat(table,"1 "); else strcat(table,"0 "); 
  if (digitalRead(COUT)==HIGH) strcat(table,"1\n"); else strcat(table,"0\n"); 

  digitalWrite(A,LOW); digitalWrite(B,LOW); digitalWrite(CI,HIGH);
  strcat(table,"00 1 - ");
  if (digitalRead(RESULT)==HIGH) strcat(table,"1 "); else strcat(table,"0 "); 
  if (digitalRead(COUT)==HIGH) strcat(table,"1\n"); else strcat(table,"0\n"); 
  
  digitalWrite(A,HIGH); digitalWrite(B,LOW); digitalWrite(CI,HIGH);
  strcat(table,"10 1 - ");
  if (digitalRead(RESULT)==HIGH) strcat(table,"1 "); else strcat(table,"0 "); 
  if (digitalRead(COUT)==HIGH) strcat(table,"1\n"); else strcat(table,"0\n"); 

  digitalWrite(A,LOW); digitalWrite(B,HIGH); digitalWrite(CI,HIGH);
  strcat(table,"01 1 - ");
  if (digitalRead(RESULT)==HIGH) strcat(table,"1 "); else strcat(table,"0 "); 
  if (digitalRead(COUT)==HIGH) strcat(table,"1\n"); else strcat(table,"0\n"); 

  digitalWrite(A,HIGH); digitalWrite(B,HIGH); digitalWrite(CI,HIGH);
  strcat(table,"11 1 - ");
  if (digitalRead(RESULT)==HIGH) strcat(table,"1 "); else strcat(table,"0 "); 
  if (digitalRead(COUT)==HIGH) strcat(table,"1\n"); else strcat(table,"0\n"); 

  return table;
}


void TestXor(void) {
  char *pLine;
  digitalWrite(ENA,   HIGH);
  digitalWrite(MODE,  LOW);
  digitalWrite(F1,    HIGH);
  digitalWrite(F2,    HIGH);
  digitalWrite(F2_,   LOW);
  digitalWrite(BCLR_, HIGH);
  digitalWrite(BSET_, HIGH);
  digitalWrite(BINV,  LOW);
  pLine=Scan();
  Serial.println("\n*** XOR ***\n");
  Serial.println(pLine); 
}


void TestOr(void) {
  char *pLine;
  digitalWrite(ENA,   HIGH);
  digitalWrite(MODE,  LOW);
  digitalWrite(F1,    LOW);
  digitalWrite(F2,    HIGH);
  digitalWrite(F2_,   LOW);
  digitalWrite(BCLR_, HIGH);
  digitalWrite(BSET_, HIGH);
  digitalWrite(BINV,  LOW);
  pLine=Scan();
  Serial.println("\n*** OR ***\n");
  Serial.println(pLine); 
}

void TestAnd(void) {
  char *pLine;
  digitalWrite(ENA,   HIGH);
  digitalWrite(MODE,  LOW);
  digitalWrite(F1,    LOW);
  digitalWrite(F2,    LOW);
  digitalWrite(F2_,   HIGH);
  digitalWrite(BCLR_, HIGH);
  digitalWrite(BSET_, HIGH);
  digitalWrite(BINV,  LOW);
  pLine=Scan();
  Serial.println("\n*** AND ***\n");
  Serial.println(pLine); 
}


void TestZero(void) {
  char *pLine;
  digitalWrite(ENA,   HIGH);
  digitalWrite(MODE,  LOW);
  digitalWrite(F1,    LOW);
  digitalWrite(F2,    LOW);
  digitalWrite(F2_,   HIGH);
  digitalWrite(BCLR_, LOW);
  digitalWrite(BSET_, HIGH);
  digitalWrite(BINV,  LOW);
  pLine=Scan();
  Serial.println("\n*** ZERO ***\n");
  Serial.println(pLine); 
}

void TestOne(void) {
  char *pLine;
  digitalWrite(ENA,   HIGH);
  digitalWrite(MODE,  LOW);
  digitalWrite(F1,    LOW);
  digitalWrite(F2,    LOW);
  digitalWrite(F2_,   HIGH);
  digitalWrite(BCLR_, HIGH);
  digitalWrite(BSET_, LOW);
  digitalWrite(BINV,  LOW);
  pLine=Scan();
  Serial.println("\n*** ONE ***\n");
  Serial.println(pLine); 
}

void TestNot(void) {
  char *pLine;
  digitalWrite(ENA,   HIGH);
  digitalWrite(MODE,  LOW);
  digitalWrite(F1,    HIGH);
  digitalWrite(F2,    HIGH);
  digitalWrite(F2_,   LOW);
  digitalWrite(BCLR_, HIGH);
  digitalWrite(BSET_, LOW);
  digitalWrite(BINV,  LOW);
  pLine=Scan();
  Serial.println("\n*** ZERO ***\n");
  Serial.println(pLine); 
}


void TestInc(void) {
  char *pLine;
  digitalWrite(ENA,   HIGH);
  digitalWrite(MODE,  HIGH);
  digitalWrite(F1,    HIGH);
  digitalWrite(F2,    HIGH);
  digitalWrite(F2_,   LOW);
  digitalWrite(BCLR_, LOW);
  digitalWrite(BSET_, HIGH);
  digitalWrite(BINV,  HIGH);
  pLine=Scan();
  Serial.println("\n*** INC ***\n");
  Serial.println(pLine); 
}

void TestDec(void) {
  char *pLine;
  digitalWrite(ENA,   HIGH);
  digitalWrite(MODE,  HIGH);
  digitalWrite(F1,    HIGH);
  digitalWrite(F2,    HIGH);
  digitalWrite(F2_,   LOW);
  digitalWrite(BCLR_, HIGH);
  digitalWrite(BSET_, LOW);
  digitalWrite(BINV,  LOW);
  pLine=Scan();
  Serial.println("\n*** DEC ***\n");
  Serial.println(pLine); 
}


void loop() {
}

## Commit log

2015-07-07 Files for UART RX
2015-07-13 Removed neg voltage and one level shifter diode
2015-07-13 Added comment/heading in schematics
2015-07-13 Added voltage-in for TX fakers
2015-07-13 Added cap to get filtering of spurs from data-line
2015-07-13 Removed testharness from UART-RX to own modolu
2015-07-13 Added octal addressable latch to UART-RX
2015-07-15 Added 12-step ringcounter for UART-TX
2015-07-15 Added layouts for donut-pcbs
2015-07-15 Added calculator for resistor divider
2015-07-15 Eagle files
    [Lab-3NANDx8.brd, Lab-3NANDx8.sch, Lab-FullAdder.brd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]
2015-07-17 Half done assembler for cpu
2015-07-20 Now two-pass assembler that can resolve forward references
2015-07-24 Added tcp server for emulating uart on in/out[15]
2015-07-27 Frontpanel design
    [Frontpanel.brd]
2015-07-27 Uart rx/tx working
2015-08-27 General flush of files
    [Board.brd, Board.sch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]
